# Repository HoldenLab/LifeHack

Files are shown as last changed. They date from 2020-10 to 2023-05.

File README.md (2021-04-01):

# LifeHack
**Open source SMLM microscope designs**

This GitHub repository contains all the designs needed to construct and set up your own version of the LifeHack microsope.

The full microscope CAD designs are available to view online and download through Autodesk's A360.com platform.

<a href="https://a360.co/34cZwOU">View CAD Design Online</a>

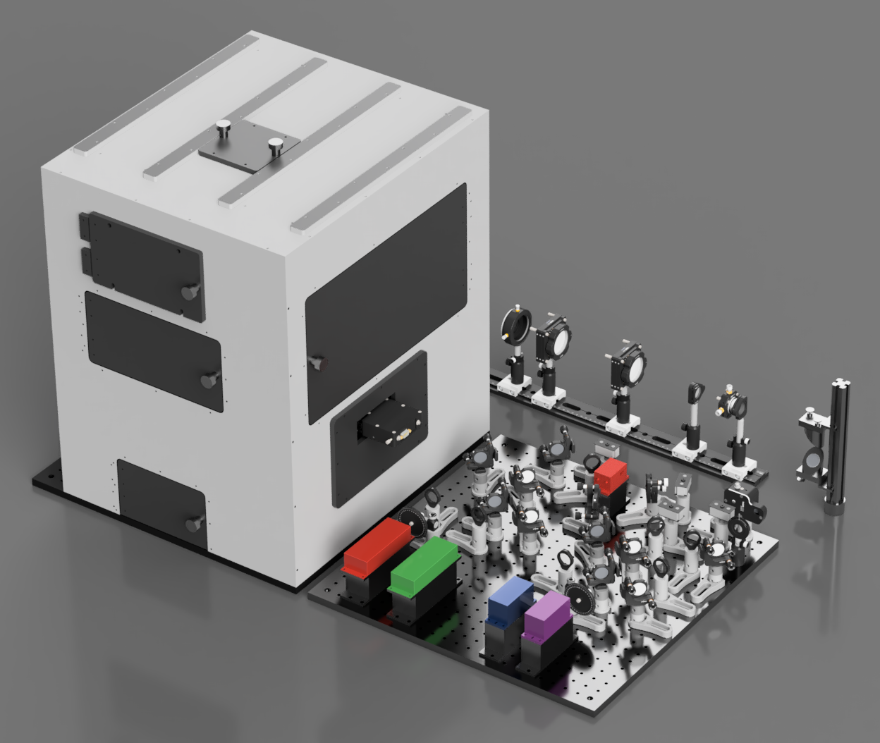
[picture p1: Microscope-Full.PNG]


The LifeHack microscope is an open-source system designed to provide an easily modifiable, modular platform for live cell SMLM imaging. It has been contructed from comercially available and 3D printed parts to simply the build process while retaining adaptability.

For full documentation please see the <a href="">LifeHack website</a>

### Change Log

  <ul>
    <li><b>24th February 2021:</b> Initial release of all modules </li>
    <li><b>1st April 2021:</b> Reduced diameter of 100mm beam expansion lens from 2" to 1"</li>
  </ul>

<br />This work is licensed under a <a rel="license" href="http://creativecommons.org/licenses/by-nc-sa/4.0/">Creative Commons Attribution-NonCommercial-ShareAlike 4.0 International License</a>.

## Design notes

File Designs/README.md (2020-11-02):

# Designs

This folder contains the necessary designs to replicate the LifeHack microscope system. The included subfolders contain; [3D Models](https://github.com/Joshedwards222/LifeHack/blob/master/Designs/CAD) intended as the main reference point for any build, [Line Diagrams](https://github.com/Joshedwards222/LifeHack/blob/master/Designs/Line_drawings) to show the principles of operation optically and electronically, and a full list of [Parts](https://github.com/Joshedwards222/LifeHack/blob/master/Designs/Parts) and induvidual designs for 3D printable components.

## LifeHack Build/Alignment Tips

### Contents
* [Using This Document](https://github.com/Joshedwards222/LifeHack/blob/master/Designs/README.md#using-this-document)
* [Main Body](https://github.com/Joshedwards222/LifeHack/blob/master/Designs/README.md#main-body)
    * [Infinity Cubes](https://github.com/Joshedwards222/LifeHack/blob/master/Designs/README.md#infinity-cubes)
* [Excitation Module](https://github.com/Joshedwards222/LifeHack/blob/master/Designs/README.md#excitation-module)
* [Beam Expansion Module](https://github.com/Joshedwards222/LifeHack/blob/master/Designs/README.md#beam-expansion-module)
* [Connecting Modules](https://github.com/Joshedwards222/LifeHack/blob/master/Designs/README.md#connecting-modules)
* [Incubation Box/Heater](https://github.com/Joshedwards222/LifeHack/blob/master/Designs/README.md#incubation-box/heater)
    * [Air Diffusers](https://github.com/Joshedwards222/LifeHack/blob/master/Designs/README.md#air-diffusers)
    * [Adding the Box to the System](https://github.com/Joshedwards222/LifeHack/blob/master/Designs/README.md#adding-the-box-to-the-system)
    * [Heater Setup](https://github.com/Joshedwards222/LifeHack/blob/master/Designs/README.md#heater-setup)
### Using This Document

This document is designed to supplement the 3D model of the microscope not as a stand alone instruction manual. A basic level of experience in building and aligning optical systems is assumed so only areas where the build process deviates from what would be considered standard practice are specifically included.

For elements of the build relating to controlling commercially available components such as electrical connections and software please refer to the relevant manual.

### Main Body

Alignment of the main body of the microscope is greatly aided by the use of a dedicated alignment laser with interchangeable screw mounts. This allows for mounting of the laser at various ports and on sections of rail.

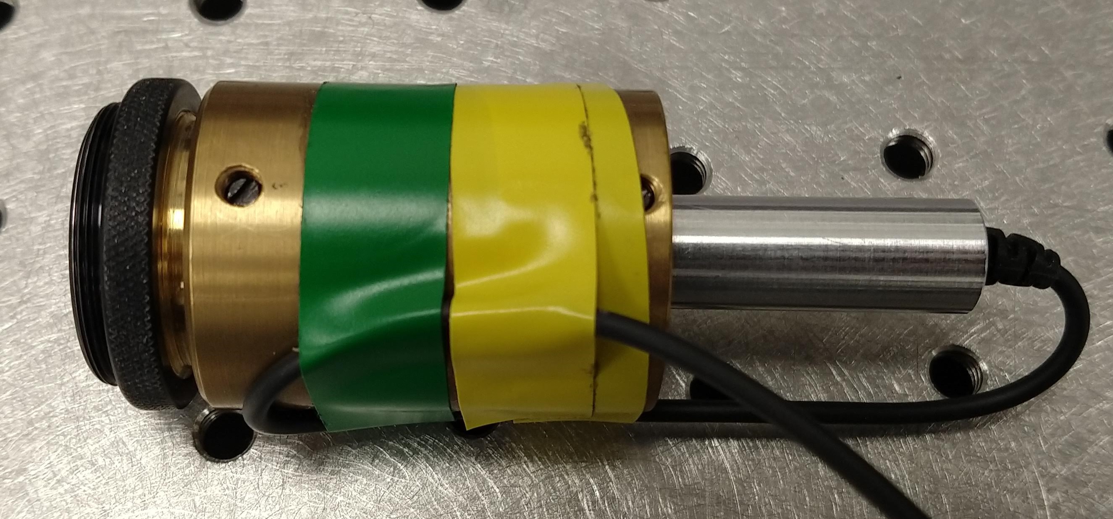
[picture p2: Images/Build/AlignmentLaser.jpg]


#### Infinity Cubes

The two vertically mounted Infinity Cubes need to have their filter cubes mounted the other way up to standard. To achieve this the top and bottom plates need to be removed and swapped before fitting in to the microscope.

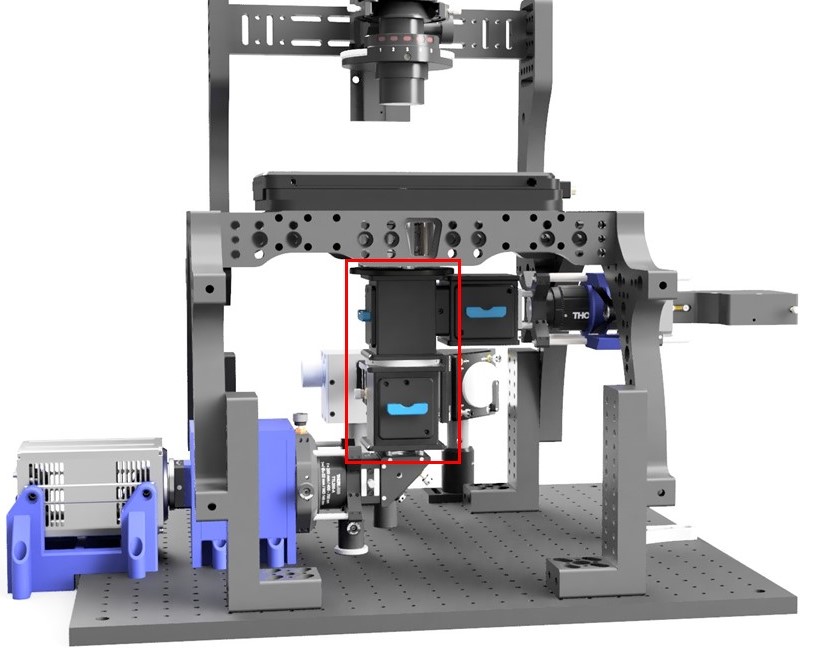
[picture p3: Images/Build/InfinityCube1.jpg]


The desired set up can be found in the microscope 3D model.

### Excitation Module

This module can be aligned with the lasers in the design by usual techniques.

### Beam Expansion Module

This module is best aligned using the output from the excitation module and as such should be built following that module. Alignment can be conducted with usual techniques.

### Connecting Modules

As the Main Body and Excitation modules are self contained on boards they can be built and then moved into place if convenient. Once the three modules are aligned individually and in place they need to be aligned to eachother. Assuming you have already used the Excitation Module to align the Beam Expansion Module these only need aligning collectively to the Main Body. To do this it can be useful to use the alignment laser mounted in the Main Body and a laser from the Excitation Module to give opposing beams through the system.

### Incubation Box/Heater

* After checking that you are in possession of the full set of parts tap every M4 sized hole (the electric screwdriver is a big time saver for this).
* item Before connecting the main panels together, first attach each subsidiary panel to its respective main face. 
* Following this, now attach the 5 main panels together to confirm the parts fit correctly.
* Remove the top panel and attach the felt air diffusers as shown below.

#### Air Diffusers

* Remove the "top filter mounts" from the top panel to reveal the slits beneath.
* Measure and cut the diffuser felt to fit the slits.

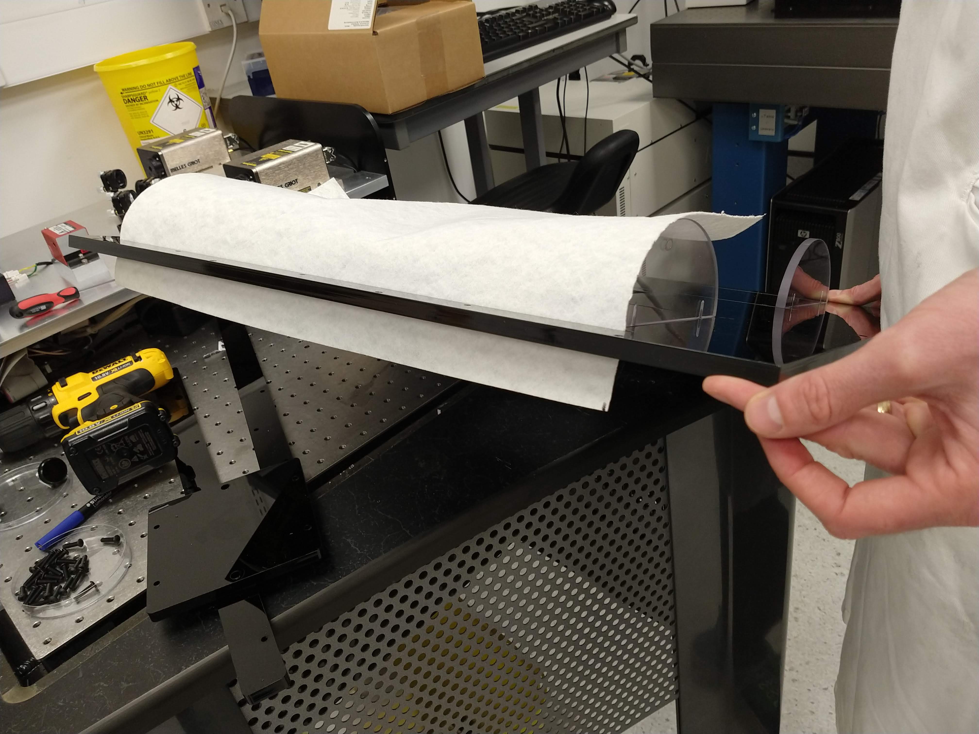
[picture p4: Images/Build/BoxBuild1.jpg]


* Pull the diffuser a short way through one of the slits and re attach the corresponding "top filter mount" to hold it in place.
* To do this, pull the diffuser to one side and attach the row of screws on the opposite side. 
* Then, using a screwdriver or similar, poke through the holes on the other side to put holes through the diffuser material and attache the screws on this side

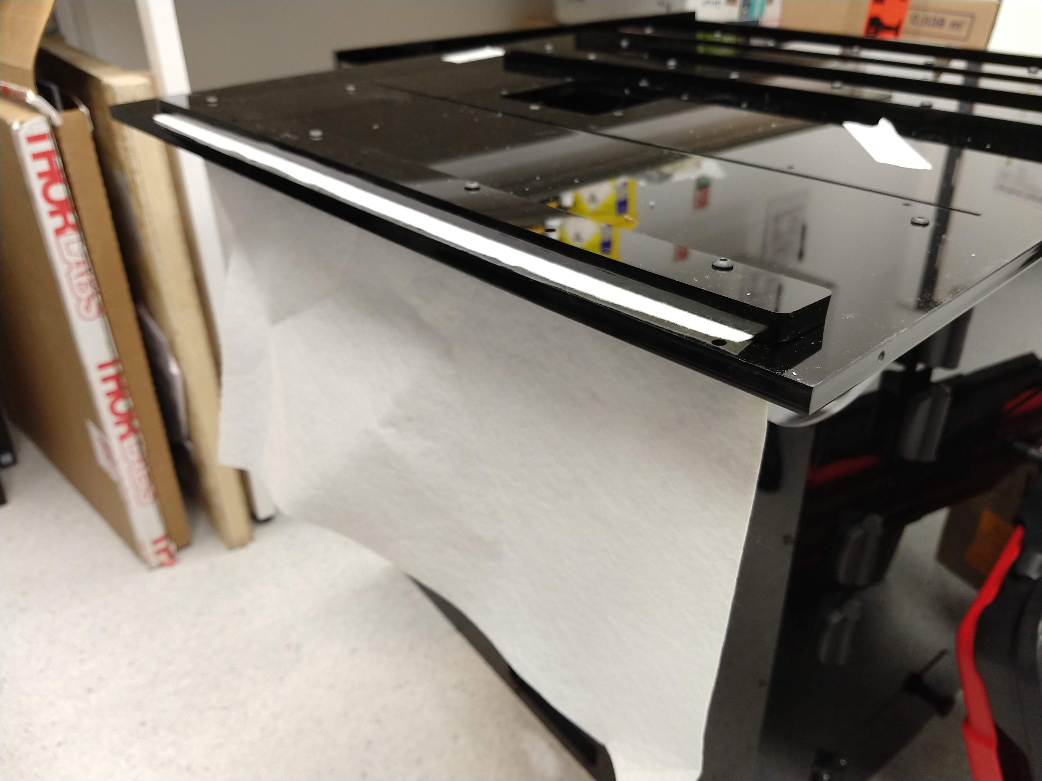
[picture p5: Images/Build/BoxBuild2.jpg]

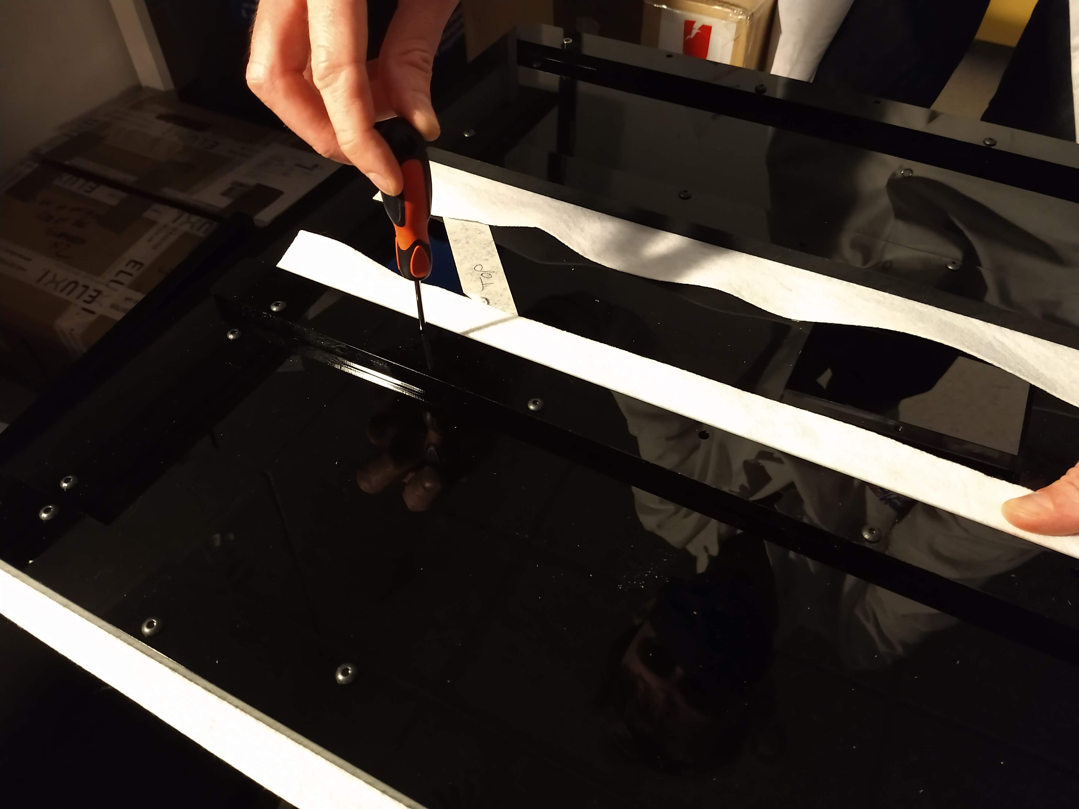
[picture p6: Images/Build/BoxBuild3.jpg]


\begin{figure}[H]
\begin{minipage}{.5\textwidth}
    \centering
        \includegraphics[width=7cm]{Figures/BoxBuild2.jpg}
        \caption{}
\end{minipage}
\begin{minipage}{.5\textwidth}
\centering
        \includegraphics[width=7cm]{Figures/BoxBuild3.jpg}
        \caption{}
\end{minipage}
\end{figure}

* Pull the loose side of the diffuser across the D-shaped diffuser mounts and pass it through the slit on the other side.
* Pull the diffuser taught across the mounts to ensure a good fit and secure it with the corresponding "top filter mount".

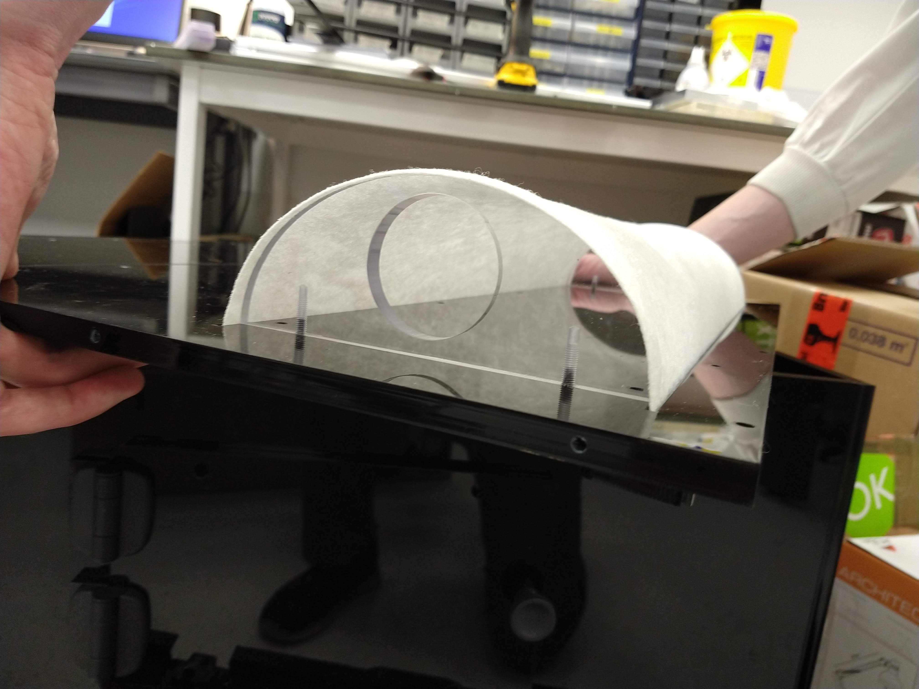
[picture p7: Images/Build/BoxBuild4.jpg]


* Repeat the above steps for the second diffuser then reattach the now completed top panel to the rest of the box. 

#### Adding the Box to the system

\begin{center}

**This is a two person job**

\end{center}

* Check the box is securely assembled before lifting.
* Open hatch doors on the two side panels and remove the "top cover" on the top panel to provide handholds.
* Remove the camera and CRISP units from the microscope "main body".
* Lift the box over the top of the "main body" and gently set it down.

#### Heater Setup

* Remove the "Back Air-hose Covers" from the box.
* Using Epoxy, for each cover attach the flared air-hose connector.

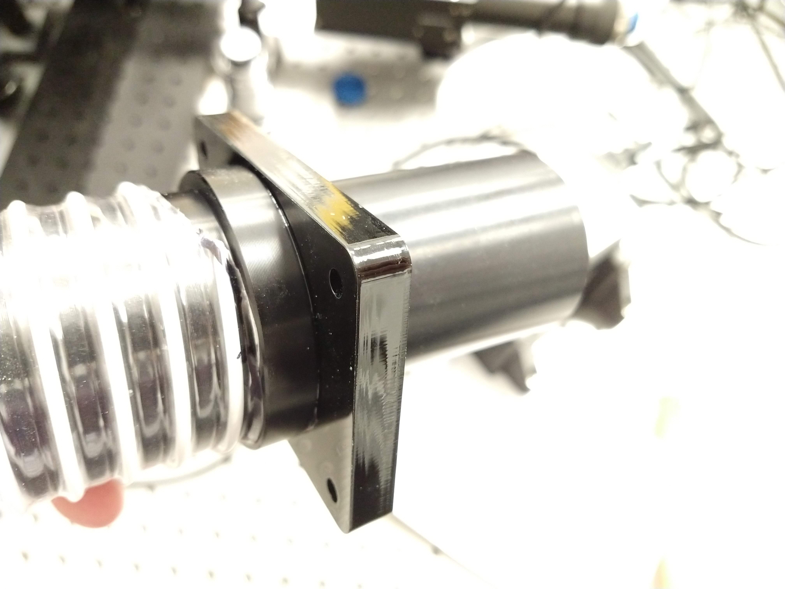
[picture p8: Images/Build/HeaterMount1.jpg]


* Allow this to set for about 20 minutes (refer to epoxy for precise time).
* For the top two "Back Air-hose covers", use the Epoxy to attach the non-flared air hose connectors from the opposite side to the flared connector.

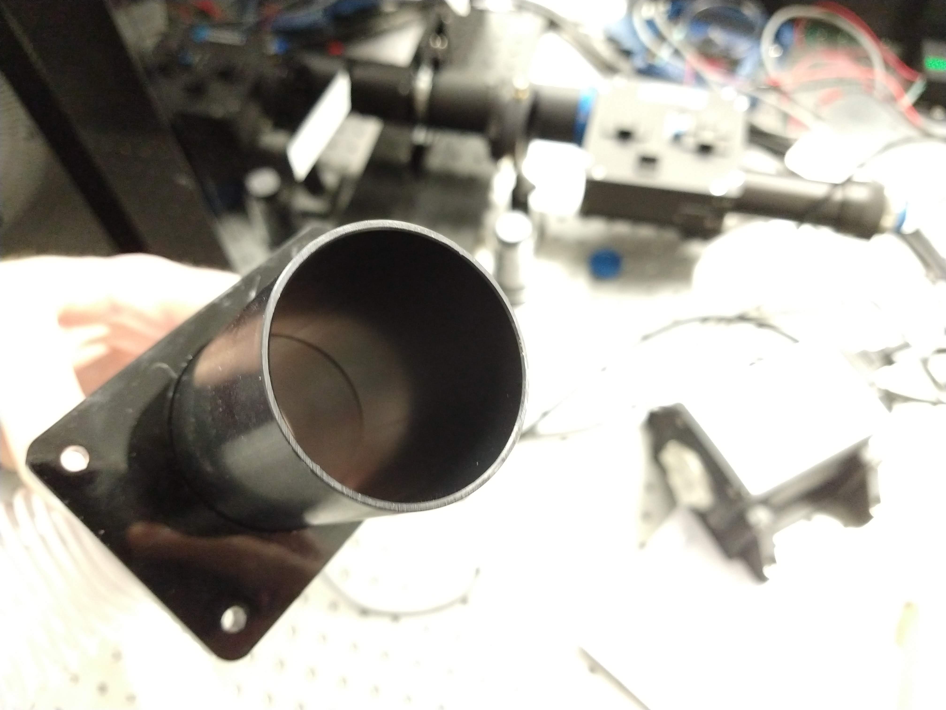
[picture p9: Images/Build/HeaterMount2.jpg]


* Leave the 4 assemblies to set for 3 hours (refer to epoxy for precise time).
* Before reattaching the assemblies to the back of the box, measure and cut the air-hose to length for each of the 4 connections.

**PUT PHOTO OF CUTTING HERE**

* Once cut, attach the air-hoses to the heater and then to the attachment assemblies (Utilise a screwing action following the direction of the structural wire in the air hose).

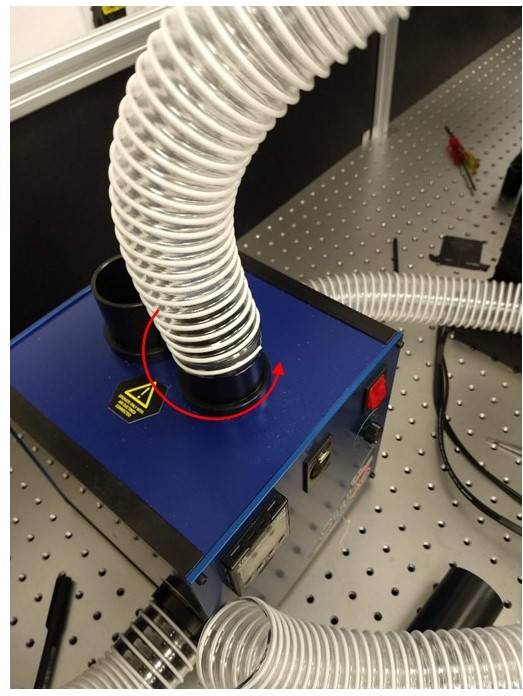
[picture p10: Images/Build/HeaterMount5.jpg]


\begin{figure}[H]
    \centering
        \includegraphics[width=10cm]{Figures/HeaterMount5.jpg}
        \caption{}
\end{figure}

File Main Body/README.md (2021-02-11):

# Main Body

This folder contains everything needed to build the Main Body. This also encompasses the Image Autofocus and Focus Shifter sub-modules

<a href="https://a360.co/3p1nkNR">View CAD Design</a> through A360.com

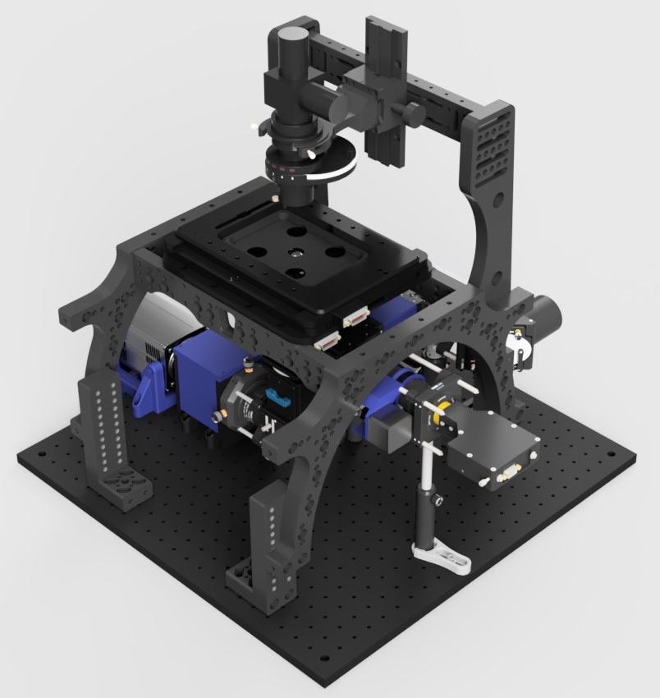
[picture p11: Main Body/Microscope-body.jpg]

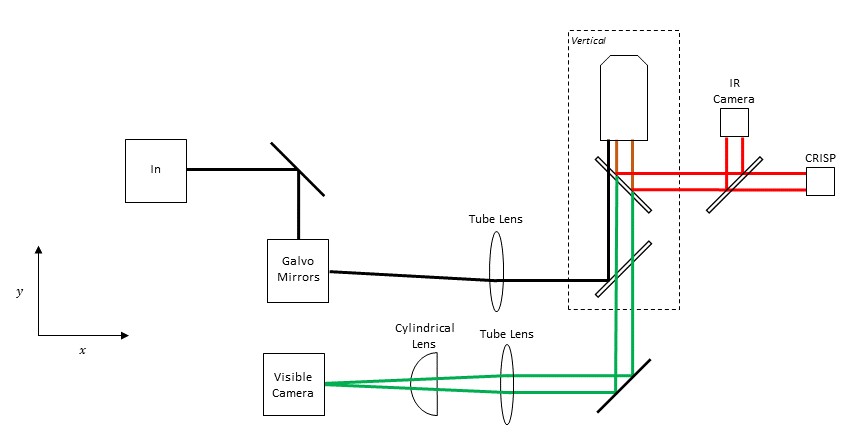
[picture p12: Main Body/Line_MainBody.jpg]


## Parts

Contains .STL files for the 3D printed components. 3D printed parts were printed on an Ultimaker 2+ using PLA with triangular infill at 30% density

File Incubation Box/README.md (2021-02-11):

# Incubation Box

This folder contains everything needed to build the Incubation box

<a href="https://a360.co/38g8Djh">View CAD Design</a> through A360.com

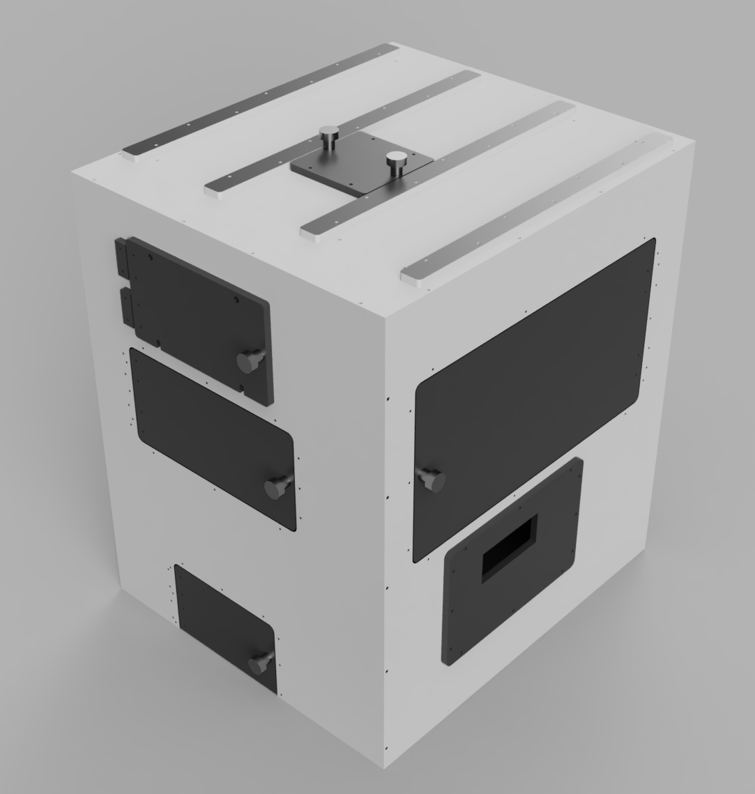
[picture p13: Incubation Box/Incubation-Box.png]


## Parts

Contains dimentioned 2D drawings of box components in .DXF form ready for production.

All parts are made from Black 9961 Perspex except the window which is made from clear Perspex.

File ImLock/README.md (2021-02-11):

# Image Autofocus Module

This folder contains everything needed to build the Image Autofocus module

<a href="https://a360.co/3p8be5k">View CAD Design</a> through A360.com

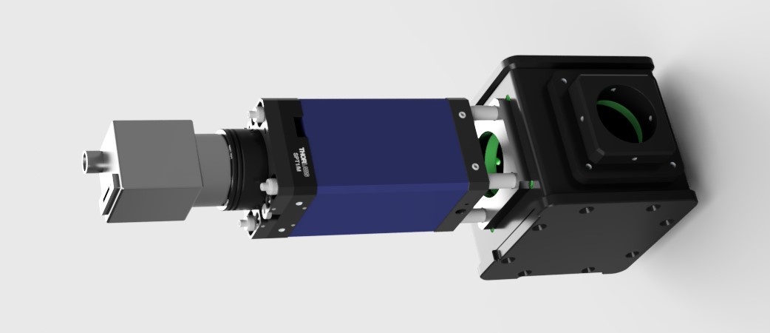
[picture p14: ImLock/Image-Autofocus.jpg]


## Parts

Contains .STL files for the 3D printed components. 3D printed parts were printed on an Ultimaker 2+ using PLA with triangular infill at 30% density.

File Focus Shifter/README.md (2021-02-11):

# FocusShifter: Arduino-based microscope autofocus control

This folder contains everything needed to build the Focus Shifter module

<a href="https://a360.co/3rbyG3y">View CAD Design</a> through A360.com

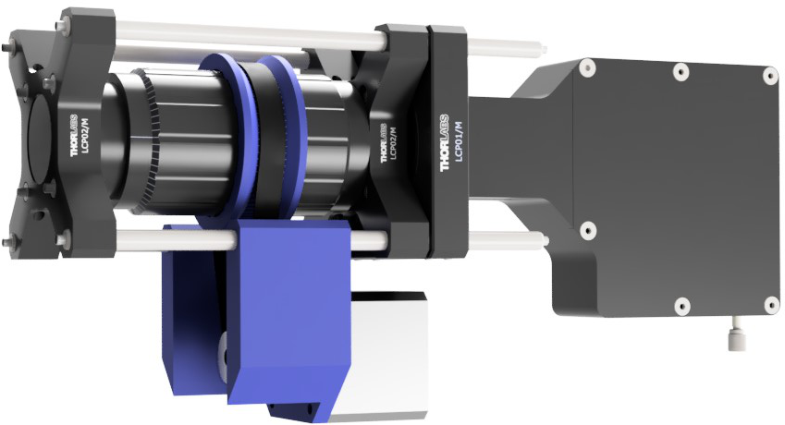
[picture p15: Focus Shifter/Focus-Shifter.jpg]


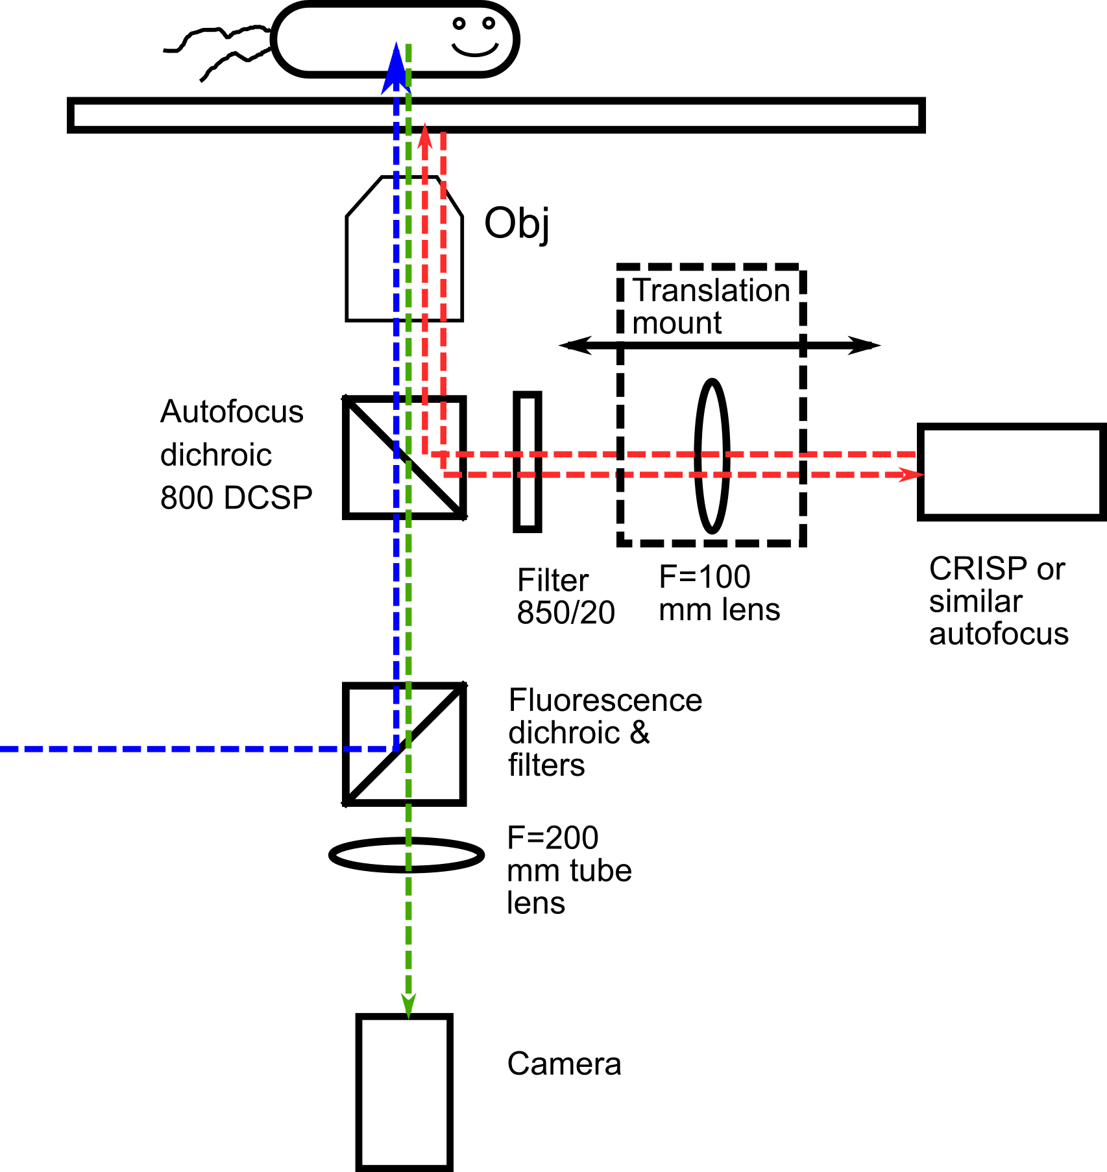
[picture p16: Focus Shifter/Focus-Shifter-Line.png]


## Parts

Contains .STL files for the 3D printed components. 3D printed parts were printed on an Ultimaker 2+ using PLA with triangular infill at 30% density.

## Software

Contains arduino control software.

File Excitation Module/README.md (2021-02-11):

# Excitation Module

This folder contains everything needed to build the excitation module

<a href="https://a360.co/3mF2ceR"> View CAD Design</a> through A360.com

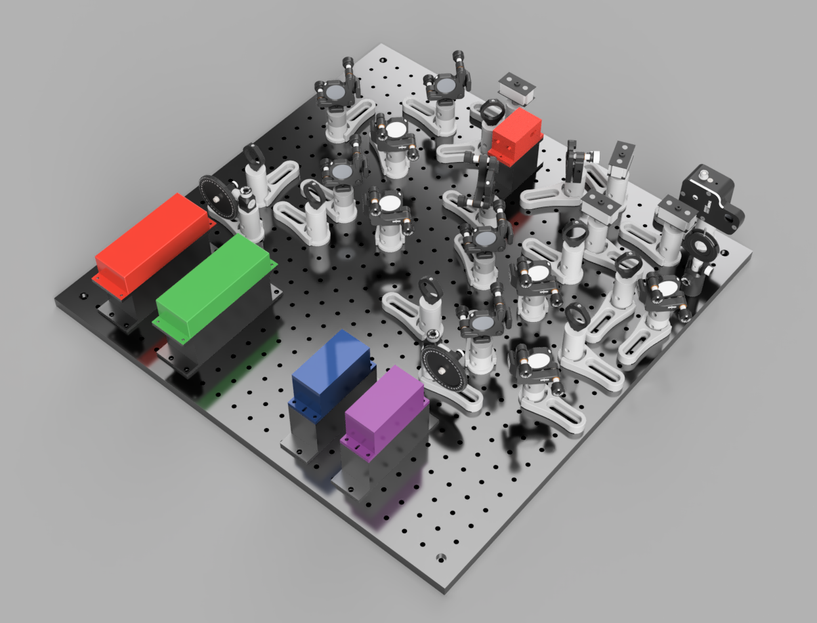
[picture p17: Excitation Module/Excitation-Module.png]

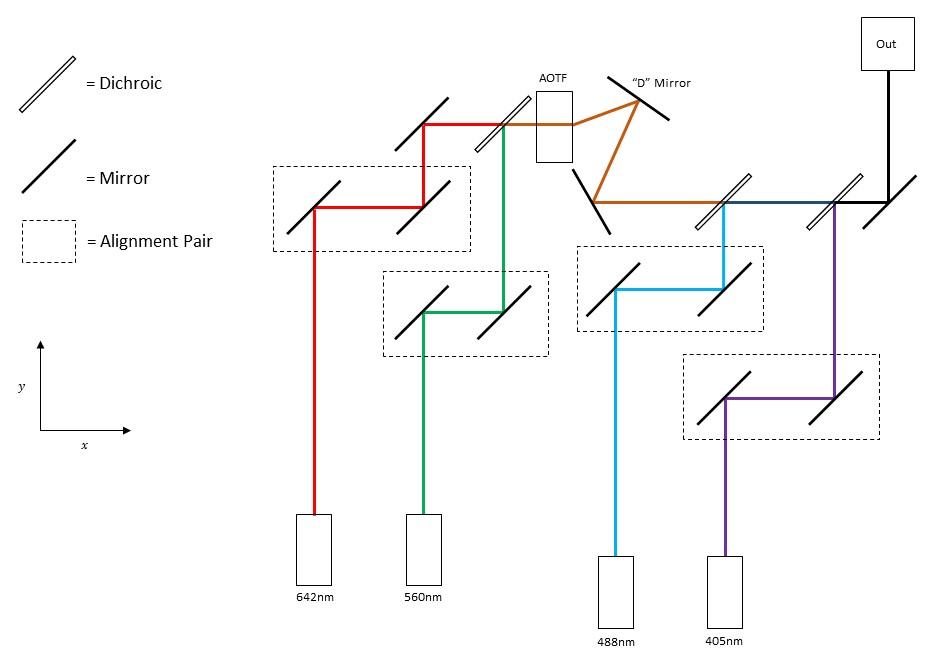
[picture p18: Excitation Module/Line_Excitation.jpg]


## Parts

Contains .STL files for the 3D printed components. 3D printed parts were printed on an Ultimaker 2+ using PLA with triangular infill at 30% density

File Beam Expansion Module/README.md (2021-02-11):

# Beam Expansion Module

This folder contains everything needed to build the Beam Expansion Module

<a href="https://a360.co/3h2i9KU">View CAD Design</a> through A360.com

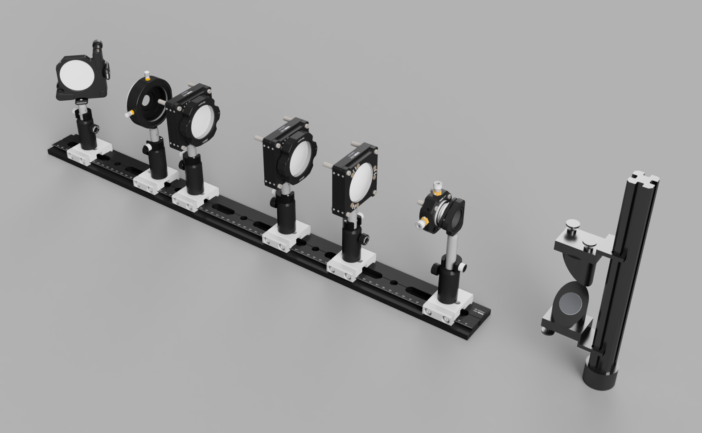
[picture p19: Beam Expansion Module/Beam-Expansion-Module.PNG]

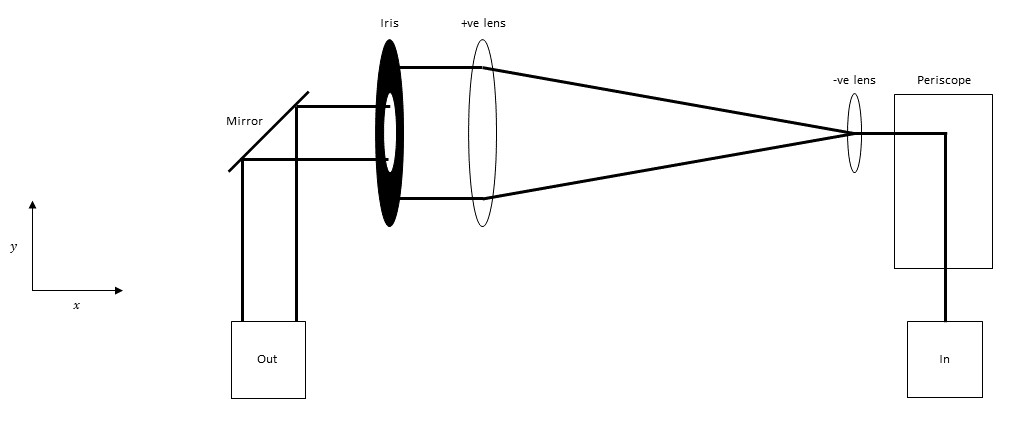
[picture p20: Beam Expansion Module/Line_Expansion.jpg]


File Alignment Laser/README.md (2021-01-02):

# Alignment Laser

Designs for a laser mount to allow for attachment to the system via an RMS thread

<image src="AlignmentLaser.jpg" width=500px>

Adapted from Design in <a href="https://www.osapublishing.org/oe/fulltext.cfm?uri=oe-23-6-7734&id=313825">S. Abrahamsson et al, "MultiFocus Polarization Microscope (MF-PolScope) for 3D polarization imaging of up to 25 focal planes simultaneously," Opt. Express 23, 7734-7754 (2015)</a>

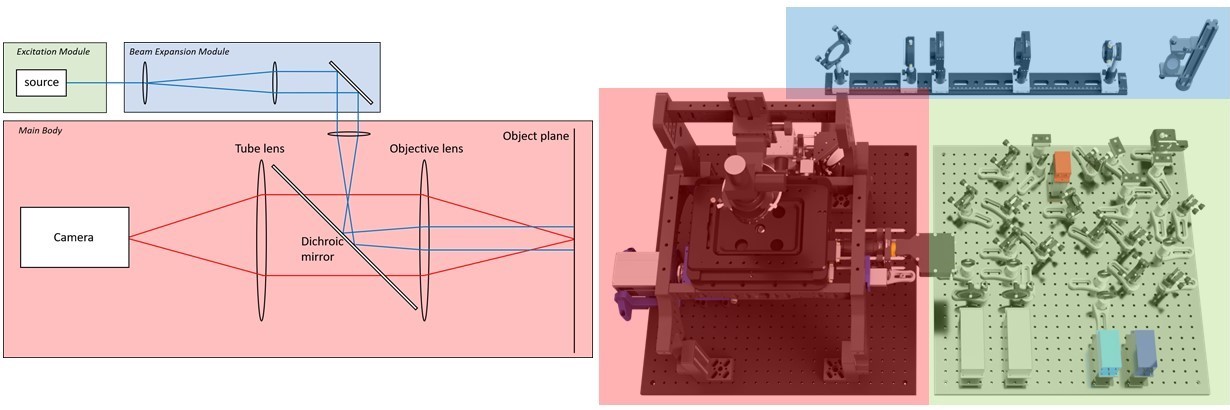
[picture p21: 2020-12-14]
Module-Structure.jpg

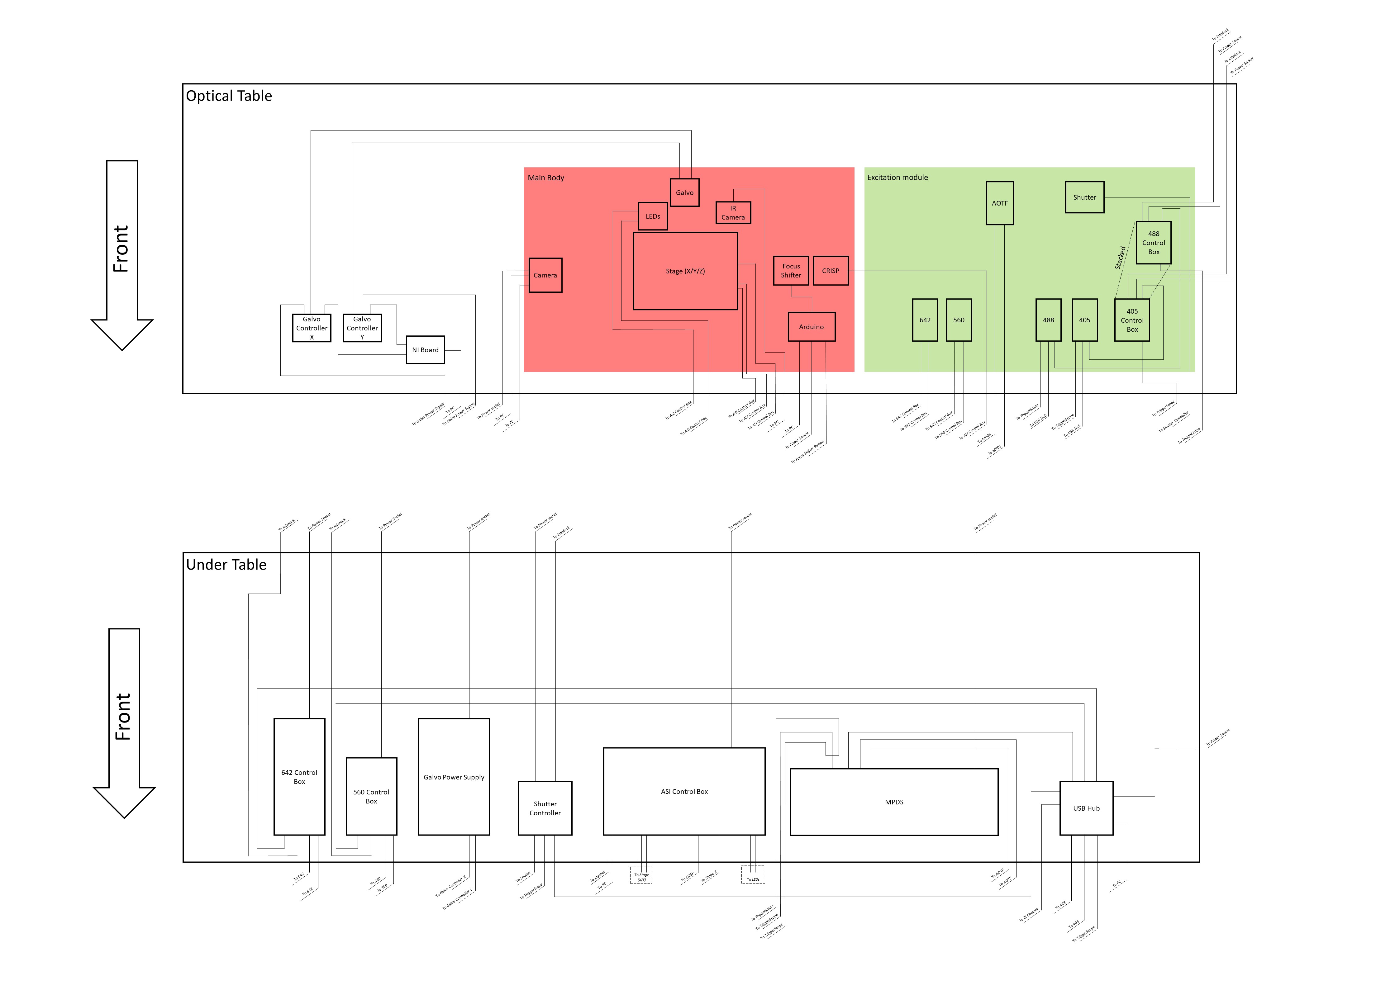
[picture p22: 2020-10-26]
Modules/Circuit Diagram.jpg

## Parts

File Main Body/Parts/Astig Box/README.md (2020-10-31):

# Astigmatic Lens Box

The body of the box should be printed in the same orientation as it sits in the microscope but the lid should be printed upside down with the top face against the build plate

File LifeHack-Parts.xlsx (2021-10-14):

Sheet: Excitation Module
Parts List
 | Part number | Supplier | Quantity | Price | Subtotal
Breadboard baseplate 600 mm | 715-6060-BL | EKSMA | 1 | £546.00 | £546.00
KINEMATIC MIRROR
kinematic mirror mount (KM) | KM100CP/M | Thorlabs | 11 | £53.93 | £593.23
pillar post,Ø 25mm, L19mm,M6 tap,M4 adaptot included | RS19/M | Thorlabs | 11 | £13.69 | £150.59
pedestal pillar post,Ø 25mm,M6taps,L25mm | RS1P/M | Thorlabs | 11 | £17.21 | £189.31
clamp for KM | CF125 | Thorlabs | 11 | £6.71 | £73.81
Ø1" Broadband Dielectric Mirror, 400 - 750 nm, 10 Pack | BB1-E02-10 | Thorlabs | 1 | £506.93 | £506.93
Ø1" Broadband Dielectric Mirror, 400 - 750 nm | BB1-E02 | Thorlabs | 1 | £56.33 | £56.33
OPTIC HOLDER
Fixed, Ø 1inch, mirror mount, M4 tap | FMP1/M | Thorlabs | 7 | £12.09 | £84.63
pedestal pillar post,Ø 25mm,M6taps,L50mm | RS2P/M | Thorlabs | 7 | £20.46 | £143.22
Post Spacer, Ø25 mm, Thickness = 4mm | RS4M | Thorlabs | 7 | £5.58 | £39.06
clamp for OH | CF125 | Thorlabs | 7 | £6.71 | £46.97
HALF-MIRROR/D Mirror
Left-Handed Kinematic Mount for Ø1" D-Shaped Mirrors | KM100DL | Thorlabs | 1 | £62.69 | £62.69
pedestal pillar post,Ø 25mm,M6taps,L38mm | RS1.5P/M | Thorlabs | 1 | £20.46 | £20.46
Post Spacer, Ø25 mm, Thickness = 6mm | RS6M | Thorlabs | 1 | £5.78 | £5.78
clamp for HM | CF125 | Thorlabs | 1 | £6.71 | £6.71
Ø1" Broadband Dielectric D-Shaped Mirror, 400 - 750 nm | BBD1-E02 | Thorlabs | 1 | £64.42 | £64.42
BEAM DUMPS
Beam Block, 400 - 700 nm, 10 WPower, CW Only, Includes TR75/M Post | LB1/M | Thorlabs | 4 | £37.87 | £151.48
Pedestal Pillar Post, Ø25.0 mm,M6 Taps, L = 50 mm | RS2P/M | Thorlabs | 4 | £21.61 | £86.44
Post Spacer, Ø25 mm, Thickness = 7mm | RS7M | Thorlabs | 4 | £5.13 | £20.52
clamp for BD | CF125 | Thorlabs | 4 | £6.71 | £26.84
Adapter with Internal M4 x 0.7 Threads and External M6 x 1.0 Threaded Stud | AS4M6M | Thorlabs | 4 | £3.40 | £13.60
Updated ELECTRONIC SHUTTER
Optical Beam Shutter with 10' Long Cable, Ø1/2" Aperture, M4 Tap | SH05/M | Thorlabs | 1 | £363.25 | £363.25
K-Cube Solenoid Controller (Power Supply Not Included) | KSC101 | Thorlabs | 1 | £451.49 | £451.49
15 V, 2.4 A Power Supply Unit with 3.5 mm Jack Connector for One K- or T-Cube | KPS101 | Thorlabs | 1 | £25.75 | £25.75
pedestal pillar post,Ø 25mm,M4taps,L50mm | RS2P4M | Thorlabs | 1 | £19.48 | £19.48
clamp for ES | CF125 | Thorlabs | 1 | £6.71 | £6.71
ND filters
Mounted Continuously Variable ND Filter, Ø50 mm, OD: 0-4.0, ARC: 350 - 700nm | NDC-50C-4M-A | Thorlabs | 2 | £387.95 | £775.90
Pedestal Pillar Post, M6 Taps, L = 50 mm | RS2P/M | Thorlabs | 2 | £21.71 | £43.42
Right-Angle End Clamp for Ø1/2" Posts, M6 Stud and 5 mm Hex | RA180/M | Thorlabs | 2 | £8.60 | £17.20
Ø12.7 mm Optical Post, SS, M4 Setscrew, M6 Tap, L = 30 mm | TR30/M | Thorlabs | 2 | £3.66 | £7.32
clamp for ND | CF125 | Thorlabs | 2 | £6.71 | £13.42
IRIS
Iris | ID25/M | Thorlabs | 1 | £45.65 | £45.65
Ø1/2" Post Holder | PH40/M | Thorlabs | 1 | £5.58 | £5.58
Ø1/2" Post | TR40/M | Thorlabs | 1 | £3.84 | £3.84
M6 Setscrew (5 pack) | SS6MS12 | Thorlabs | 1 | £4.58 | £4.58
Post Collar | R2M | Thorlabs | 1 | £3.85 | £3.85
Locator Screws
Adapter with External M6 x 1.0 Threads and External M4 x 0.7 Threads | AP6M4M | Thorlabs | 24 | £1.58 | £37.92
Excitation filters -chroma
405nm notch filter | ZET405/20X | Chroma | 1 | £237.00 | £237.00
488nm notch filter | ZET488/10x | Chroma | 1 | £237.00 | £237.00
561nm notch filter | ZET561/10x | Chroma | 1 | £237.00 | £237.00
642nm notch filter | ZET642/20x | Chroma | 1 | £237.00 | £237.00
Excitation dichroics
561/642 Dichroic combiner Ø25mm | DCM14 | Newport | 1 | £208.00 | £208.00
488/561 Dichroic combiner Ø25mm | DCM12 | Newport | 1 | £208.00 | £208.00
405/488 Dichroic combiner Ø25mm | DCM10 | Newport | 1 | £208.00 | £208.00
Custom mounts
405 nm mount | - | Protolabs | 1 | £192.20 | £192.20
488 nm mount | - | Protolabs | 1 | £192.20 | £192.20
561 nm mount | - | 3D printed | 1 | £0.00 | £0.00
642 nm mount | - | 3D printed | 1 | £0.00 | £0.00
AOTF mount | - | 3D printed | 1 | £0.00 | £0.00
Lasers
Stradus 405nm 100mW | 11098 | Laser 2000 | 1 | £4350.00 | £4350.00
Stradus 488nm 150mW | 11101 | Laser 2000 | 1 | £7650.00 | £7650.00
MPB Visible Fibre Laser 560nm, 300mW OEM | VFL-P-300-560-OEM1-B1 | Eluxi | 1 | £15717.75 | £15717.75
MPB Visible Fibre Laser 642nm, 1W OEM | VFL-P-1000-642-OEM1-B1 | Eluxi | 1 | £9036.00 | £9036.00
MPB External Power Supply For VFL | VFL-POWER-SUPPLY-150 | Eluxi | 2 | £350.00 | £700.00
AOTF
AOTF | AOTFnC-400.650-TN | Photon Lines | 1 | £2250.00 | £2250.00
MPDS, AOTF Driver | MPDS8C-D66-22-xx.xx | Photon Lines | 1 | £3035.00 | £3035.00
RF cable, SMA-SMA, 2m | CBL-SAM200SAM-RG223 | Photon Lines | 1 | £16.00 | £16.00
RSTAB cable, SMC-SMC, 2m | CBL-SCF200SCF-RG316 | Photon Lines | 1 | £26.00 | £26.00
TOTAL |  |  |  |  | £49451.53

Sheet: Beam Expansion Module
 | Supplier | Part number | Price | Quantity | Subtotal | Notes
Periscope
Rail Periscope, 8.9 in. Height, 1 in. Mirrors, Magnetic Pedestal Base | Newport | BSD-2R | £528 | 1 | £528.00
Ø1" Broadband Dielectric Mirror, 400 - 750 nm | Thorlabs | BB1-E02 | £58.01 | 2 | £116.02
Negative Lens
30 mm Cage System, XY Translating Lens Mount for Ø1" Optics | Thorlabs | CXY1 | £140.40 | 1 | £140.40
Ø12.7 mm Post Holder, Spring-Loaded Hex-Locking Thumbscrew, L=50 mm | Thorlabs | PH50/M | £5.95 | 1 | £5.95
Coupler, External Threads, 0.5" Long | Thorlabs | SM1T2 | £16.16 | 1 | £16.16
Magnetic Quick-Release Carriage Set, M4 Tap | Thorlabs | KB1P/M | £39.77 | 1 | £39.77
M6 x 1.0 Stainless Steel Setscrew with Hex on Both Ends, 16 mm Long, Pack of 10 | Thorlabs | SS6M16D | £9.18 | 1 | £9.18
Low-Profile T-Nut, M6 Tapped Hole, Qty: 10 | Thorlabs | XE25T3/M | £7.96 | 1 | £7.96
Ø12.7 mm Optical Post, SS, M4 Setscrew, M6 Tap, L = 75 mm | Thorlabs | TR75/M | £4.19 | 1 | £4.19
Clamping Platform for 66 mm Rails, 1/4" Counterbored Slot, 40 mm Long | Thorlabs | XT66C4 | £22.73 | 1 | £22.73
Ø1" OD Adapter for Ø1/2" Optic, 0.25" Thick | Thorlabs | AD1 | £12.42 | 1 | £12.42
f = -30.0 mm, Ø1/2" Achromatic Doublet, ARC: 400 - 700 nm | Thorlabs | ACN127-030-A | £46.07 | 1 | £46.07
Post Collar (5 pack) | Thorlabs | R2/M-P5 | £19.31 | 1 | £19.31
Positive Lens
60 mm Cage Plate, SM2 Threads, 0.5" Thick, M4 Tap (Two SM2RR Retaining Rings Included) | Thorlabs | LCP01/M | £30.84 | 2 | £61.68
60 mm Removable Cage Plate | Thorlabs | LCP90F | £52.97 | 2 | £105.94
Ø12.7 mm Post Holder, Spring-Loaded Hex-Locking Thumbscrew, L=50 mm | Thorlabs | PH50/M | £5.95 | 2 | £11.90
Ø12.7 mm Optical Post, SS, M4 Setscrew, M6 Tap, L = 50 mm | Thorlabs | TR50/M | £4.01 | 2 | £8.02
M6 x 1.0 Stainless Steel Setscrew with Hex on Both Ends, 16 mm Long, Pack of 10 | Thorlabs | SS6M16D | £9.18 | 0 | £0.00 | Multipack in Negative lens section
Low-Profile T-Nut, M6 Tapped Hole, Qty: 10 | Thorlabs | XE25T3/M | £7.96 | 0 | £0.00 | Multipack in Negative lens section
Clamping Platform for 66 mm Rails, 1/4" Counterbored Slot, 40 mm Long | Thorlabs | XT66C4 | £22.73 | 2 | £45.46
f = 200.0 mm, Ø2" Achromatic Doublet, ARC: 400 - 700 nm | Thorlabs | AC508-200-A | £84.41 | 1 | £84.41
f = 400.0 mm, Ø2" Achromatic Doublet, ARC: 400 - 700 nm | Thorlabs | AC508-400-A | £84.41 | 1 | £84.41
Post Collar | Thorlabs | R2/M | £3.86 | 0 | £0.00 | Multipack in Negative lens section
Small Positive lens
Ø12.7 mm Post Holder, Spring-Loaded Hex-Locking Thumbscrew, L=50 mm | Thorlabs | PH50/M | £5.95 | 1 | £5.95
Magnetic Quick-Release Carriage Set, M4 Tap | Thorlabs | KB1P/M | £39.77 | 1 | £39.77
M6 x 1.0 Stainless Steel Setscrew with Hex on Both Ends, 16 mm Long, Pack of 10 | Thorlabs | SS6M16D | £9.18 | 0 | £0.00 | Multipack in Negative lens section
Low-Profile T-Nut, M6 Tapped Hole, Qty: 10 | Thorlabs | XE25T3/M | £7.96 | 0 | £0.00 | Multipack in Negative lens section
Ø12.7 mm Optical Post, SS, M4 Setscrew, M6 Tap, L = 75 mm | Thorlabs | TR75/M | £4.19 | 1 | £4.19
Clamping Platform for 66 mm Rails, 1/4" Counterbored Slot, 40 mm Long | Thorlabs | XT66C4 | £22.73 | 1 | £22.73
Post Collar | Thorlabs | R2/M | £3.86 | 0 | £0.00 | Multipack in Negative lens section
f = 100 mm, Ø1" Achromatic Doublet, ARC: 400 - 700 nm | Thorlabs | AC254-100-A | £60.87 | 1 | £60.87
Iris
Translating Lens Mount for Ø2" Optics, 1 Retaining Ring Included, Metric | Thorlabs | LM2XY/M | £122.55 | 1 | £122.55
SM2 Ring-Actuated Iris Diaphragm (Ø1 - Ø25 mm) | Thorlabs | SM2D25D | £67.16 | 1 | £67.16
Ø12.7 mm Post Holder, Spring-Loaded Hex-Locking Thumbscrew, L=50 mm | Thorlabs | PH50/M | £5.95 | 1 | £5.95
Ø12.7 mm Optical Post, SS, M4 Setscrew, M6 Tap, L = 50 mm | Thorlabs | TR50/M | £4.01 | 1 | £4.01
M6 x 1.0 Stainless Steel Setscrew with Hex on Both Ends, 16 mm Long, Pack of 10 | Thorlabs | SS6M16D | £9.18 | 0 | £0.00 | Multipack in Negative lens section
Low-Profile T-Nut, M6 Tapped Hole, Qty: 10 | Thorlabs | XE25T3/M | £7.96 | 0 | £0.00 | Multipack in Negative lens section
Clamping Platform for 66 mm Rails, 1/4" Counterbored Slot, 40 mm Long | Thorlabs | XT66C4 | £22.73 | 1 | £22.73
Post Collar | Thorlabs | R2/M | £3.86 | 0 | £0.00 | Multipack in Negative lens section
Mirror
Kinematic Mirror Mount for Ø2" Optics with Post-Centered Front Plate, M4 Taps | Thorlabs | KM200CP/M | £81.97 | 1 | £81.97
Ø12.7 mm Post Holder, Spring-Loaded Hex-Locking Thumbscrew, L=50 mm | Thorlabs | PH50/M | £5.95 | 1 | £5.95
Ø12.7 mm Optical Post, SS, M4 Setscrew, M6 Tap, L = 50 mm | Thorlabs | TR50/M | £4.01 | 1 | £4.01
M6 x 1.0 Stainless Steel Setscrew with Hex on Both Ends, 16 mm Long, Pack of 10 | Thorlabs | SS6M16D | £9.18 | 0 | £0.00 | Multipack in Negative lens section
Low-Profile T-Nut, M6 Tapped Hole, Qty: 10 | Thorlabs | XE25T3/M | £7.96 | 0 | £0.00 | Multipack in Negative lens section
Clamping Platform for 66 mm Rails, 1/4" Counterbored Slot, 40 mm Long | Thorlabs | XT66C4 | £22.73 | 1 | £22.73
Ø2" Broadband Dielectric Mirror, 400 - 750 nm | Thorlabs | BB2-E02 | £117.41 | 1 | £117.41
Post Collar | Thorlabs | R2/M | £3.86 | 1 | £3.86
Rail
66 mm Single Dovetail Rail with Mounting Counterbores, L = 750 mm | Thorlabs | XT66SD-750 | £79.57 | 1 | £79.57
Total |  |  |  |  | £2041.39

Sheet: Main Body
Part name | Part number | Supplier | Quantity | Price | Subtotal | Notes
Breadboard baseplate 600 mm | 715-6060-BL | EKSMA | 1 | £546.00 | £546.00
ASI RAMM US-2000current with basket+condenser
RAMM FULL WITH NEWER ABTS-1066 CROSS BAR + Riser for Condenser | DASI/RAMM-FULL | ASI | 1 | £2633.84 | £2633.84
ABTS-1031 STILT (4 Pack) | DASI/RAMM-STILTS | ASI | 1 | £321.20 | £321.20
LED Lamp | DASI/LLEDWHT-AI | ASI | 1 | £682.55 | £682.55
Beamsplitter Cube | DASI/C60-SHORT-PORT1 | ASI | 1 | £441.65 | £441.65
OLYMPUS CONDENSER BRACKET ASSEMBLY | DASI/OLY-TRANS-ILLUM | ASI | 1 | £3015.27 | £3015.27 | Include 850nm LED (no regulator)
Cairn-dichroic-ASI stage custom rig
Sample Holder | DASI/I-3091 | ASI | 1 | £301.13 | £301.13
Motorized Stage | DASI/US/PZ2500-IOM | ASI | 1 | £18047.43 | £18047.43 | Includes: Objective basket if requested through Cairn research
LifeHack TriCube | S1250/CLH/003 | Cairn research | 1 | £2250.00 | £2250.00 | Includes: 2x Infinity Cubes, 1x Combiner Cube, Required adaptations
Filter Cube | P290/000/200 | Cairn research | 5 | £292.63 | £1463.15
Nikon NA1.49 100x objective (CFI SR HP Apochromat TIRF 100XC Oil) | MRD0195 | Nikon | 1 | £12445.60 | £12445.60
microscope-pathD-visEm
30 mm to 60 mm Cage Plate Adapter, M4 Tap | LCP02/M | Thorlabs | 1 | £31.65 | £31.65
60 mm Cage System Translating Lens Mount for Ø2" Optics | CXY2 | Thorlabs | 1 | £157.90 | £157.90
Right-Angle Kinematic Elliptical Mirror Mount | KCB1EC/M | Thorlabs | 1 | £156.05 | £156.05
1" Broadband Dielectric Elliptical Mirror, 400 - 750 nm | BBE1-E02 | Thorlabs | 1 | £76.10 | £76.10
Tube Lens, f = 200 mm, ARC: 350 - 700 nm | TTL200-A | Thorlabs | 1 | £372.53 | £372.53
30 mm Cage System Removable Filter Holder for Ø1" Optics | CFH2/M | Thorlabs | 1 | £86.84 | £86.84
Bertrand-lens
30 mm Cage System Removable Filter Holder for Ø1" Optics | CFH2/M | Thorlabs | 1 | £86.84 | £86.84
f = 50 mm, Ø1" Achromatic Doublet, ARC: 400 - 700 nm | AC254-050-A | Thorlabs | 1 | £60.87 | £60.87
Astig-lens
30 mm Cage System Removable Filter Holder for Ø1" Optics | CFH2/M | Thorlabs | 1 | £86.84 | £86.84
f = 1000.0 mm, Ø1", N-BK7 Mounted Plano-Convex Round Cyl Lens | LJ1516RM-A | Thorlabs | 1 | £96.58 | £96.58
cam-emission-interface
30 mm Cage Plate | CP33/M | Thorlabs | 1 | £12.67 | £12.67
C-Mount Extension Tube, 10 mm Long | CML10 | Thorlabs | 1 | £13.45 | £13.45
camera-and-mount
Zyla 4.2 Plus Camera-link | ZYLA-4.2P-CL10 | Andor | 1 | £12650.00 | £12650.00
20 - Camera mount | - | 3D printed | 1 | £0.00 | £0.00
1/4-20 UNC - 15mm cap screw |  | PB Film & Technik - Amazon | 4 |  | £0.00
mounting-optomech
30 mm to 60 mm Cage Plate Adapter, M4 Tap | LCP02/M | Thorlabs | 1 | £31.65 | £31.65
Cage Assembly Rod, 4" Long | ER4 | Thorlabs | 2 | £5.48 | £10.96
Cage Assembly Rod, 3" Long | ER3 | Thorlabs | 4 | £5.10 | £20.40
focalPathEnclosure
focalPathLid | - | 3D printed | 1 | £0.00 | £0.00
focalEnclosure-body | - | 3D printed | 1 | £0.00 | £0.00
4-40 Stainless Steel Cap Screw, 1/4" Long, 50 Pack | SH4S025 | Thorlabs | 1 | £6.01 | £6.01
M3 screws, 20mm |  |  |  |  | £0.00
Ø12.7 mm Pedestal Post Holder | PH30E/M | Thorlabs | 1 | £18.66 | £18.66
Ø12.7 mm Optical Post, L = 40 mm | TR40/M | Thorlabs | 1 | £3.84 | £3.84
microscope-pathC-excitation
2d-galvo-in-housing
2D Large Beam (10 mm) Diameter Galvo System | GVS212/M | Thorlabs | 1 | £2606.01 | £2606.01
30 mm Cage Adapter for 10 mm Galvo System | GCM012/M | Thorlabs | 1 | £149.33 | £149.33
KCB2EC_M-with-mirror
Right-Angle Kinematic Elliptical Mirror Mount | KCB2EC/M | Thorlabs | 1 | £183.01 | £183.01
2" Broadband Dielectric Elliptical Mirror, 400 - 750 nm | BBE2-E02 | Thorlabs | 1 | £148.92 | £148.92
CXY1-with-200mmTubeLens
30 mm Cage System, XY Translating Lens Mount for Ø1" Optics | CXY1 | Thorlabs | 1 | £140.40 | £140.40
f = 200.0 mm, Ø1" Achromatic Doublet, ARC: 400 - 1100 nm | AC254-200-AB | Thorlabs | 1 | £77.25 | £77.25
mounting-optomech
Cage Assembly Rod, 6" Long | ER6 | Thorlabs | 4 | £6.68 | £26.72
SM1 Lens Tube | SM1L40 | Thorlabs | 1 | £35.46 | £35.46
30 mm Cage Plate | CP33/M | Thorlabs | 2 | £12.67 | £25.34
30 mm Cage Plate | CP33/M | Thorlabs | 1 | £12.67 | £12.67
Ø12.7 mm Optical Post, L = 100 mm | TR100/M | Thorlabs | 1 | £4.54 | £4.54
Ø12.7 mm Post Holder | PH50/M | Thorlabs | 1 | £5.95 | £5.95
1"post-75mm
Clamping Fork for Ø1.5" Pedestal Post | PF175B | Thorlabs | 1 | £12.75 | £12.75
Ø25.0 mm Pillar Post, L = 75 mm | RS75/M | Thorlabs | 1 | £19.48 | £19.48
Ø25 mm Post Holder, L = 50 mm | RSH2/M | Thorlabs | 1 | £24.96 | £24.96
1"post-50mm
Ø25 mm Post Holder, L = 50 mm | RSHT2/M | Thorlabs | 1 | £24.96 | £24.96
Ø25.0 mm Pillar Post, L = 50 mm | RS50/M | Thorlabs | 1 | £17.85 | £17.85
Mounting Base, 50 mm x 75 mm x 10 mm | BA2/M | Thorlabs | 1 | £5.64 | £5.64
mirror-galvo-spacer
Cage Assembly Rod, 2" Long | ER2 | Thorlabs | 4 | £4.71 | £18.84
Cage Assembly Rod, 1" Long | ER1 | Thorlabs | 4 | £3.90 | £15.60
30 mm to 60 mm Cage Plate Adapter | LCP02/M | Thorlabs | 1 | £31.65 | £31.65
SM2 Lens Tube, 3" Thread Depth | SM2L30 | Thorlabs | 1 | £28.57 | £28.57
Ø2" UVFS Wedged Vacuum Window, AR Coating: 350 - 700 nm | WW42012 | Thorlabs | 1 | £131.29 | £131.29
Galvo control bits
1m galvo extension cable | PAA634/SPL-S6 | Thorlabs | 2 | £60.00 | £120.00 | Special Order (available on request)
1D or 2D Galvo System Linear Power Supply | GPS011-EC | Thorlabs | 1 | £392.53 | £392.53
Galvo Driver Card Cover | GCE001 | Thorlabs | 2 | £46.46 | £92.92
microscope-pathB-autofocus-crisp (Focus Shifter)
CRISP-5 ASSEMBLY | DASI/CRISP-940 | ASI | 1 | £7206.93 | £7206.93
zoom-tube-lens
SM1 Zoom Housing for Ø1" Optics | SM1NR1 | Thorlabs | 1 | £161.51 | £161.51
N-BK7 Best Form Lens, Ø1", f = 100 mm, ARC: 650-1050 nm | LBF254-100-B | Thorlabs | 1 | £42.81 | £42.81
mounting-optomech
30 mm to 60 mm Cage Plate Adapter, M4 Tap | LCP02/M | Thorlabs | 2 | £31.65 | £63.30
Cage Assembly Rod, 6" Long | ER6 | Thorlabs | 4 | £6.68 | £26.72
60 mm Cage Plate | LCP01/M | Thorlabs | 1 | £30.84 | £30.84
Adapter with External C-Mount Threads and External SM2 Threads | SM2A55 | Thorlabs | 1 | £21.71 | £21.71
support-post
Ø12.7 mm Pedestal Post Holder, L=104.7 mm | PH100E/M | Thorlabs | 1 | £20.30 | £20.30
Clamping Fork | CF125C/M | Thorlabs | 1 | £8.77 | £8.77
Ø12.7 mm Optical Post, L = 150 mm | TR150/M | Thorlabs | 1 | £5.50 | £5.50
motorMountingBits
Zoom-housing-custom-pulley | - | 3D printed | 1 | £0.00 | £0.00
RS PRO, Timing Belt, 115 Teeth, 233.68mm Length X 6mm Width | 778-5073 | RS | 1 | £2.75 | £2.75
Motor-cage-coupler | - | 3D printed | 1 | £0.00 | £0.00
motor
pulley-RS-778-4714 | 778-4714 | RS | 1 | £6.18 | £6.18
RS PRO Hybrid Stepper Stepper Motor, 12 V, 5mm Shaft Diameter | 180-5279 | RS | 1 | £23.13 | £23.13
Focus-shifter electronics
Arduino Uno | 715-4081 | RS | 1 | £17.00 | £17.00
Adafruit Motor/Stepper/Servo Shield for Arduino v2 Kit - v2.3 | 1438 | Adafruit/ https://thepihut.com | 1 | £18.50 | £18.50
PCB headers | 251-8351 | RS | 1 | £0.75 | £0.75
7.2W Plug In Power Supply | 735-0747 | RS | 1 | £11.85 | £11.85
Spade Crimp Connectors (100 Pack) | 534-339 | RS | 1 | £9.70 | £9.70
Push Button | SW05762 | CPC Farnell | 1 | £1.72 | £1.72
DPDT Rocker switch | 907-7071 | RS | 1 | £7.60 | £7.60
Arduino enclosure | - | 3D printed | 1 | £0.00 | £0.00
Serial Cable Assembly 3m Male to Female, DB9 to DB9 | 777-637 | RS | 1 | £11.52 | £11.52
RS PRO Panel Mount, 9 Pin D-sub Connector Socket, Shell Size E, Solder Cup (10 Pack) | 544-3749 | RS | 1 | £3.10 | £3.10
RS PRO Panel Mount, 9 Pin D-sub Connector Plug, Shell Size E, Solder Cup (10 Pack) | 544-3727 | RS | 1 | £3.10 | £3.10
RS PRO Female UNC 4-40 Screwlock Suitable For D Connector for use with D Connector (10 Pack) | 453-886 | RS | 1 | £6.42 | £6.42
Jumper wires | 505-3396 | RS | 1 | £4.59 | £4.59
Black hookup wire | 884-0837 | RS | 1 | £6.27 | £6.27
Red hookup wire | 874-0374 | RS | 1 | £6.27 | £6.27
microscope-pathA-imageAutofocus (Imlock)
pathA-optics
Blackfly BFS-U3-51S5 | BFS-U3-51S5M-C | FLIR | 1 | £1013.00 | £1013.00
Coarse ±1 mm XY Slip Plate Positioner | SPT1/M | Thorlabs | 1 | £49.91 | £49.91
Best Form Lens, Ø1", f = 100 mm, ARC: 650-1050 nm | LBF254-100-B | Thorlabs | 1 | £42.81 | £42.81
SM1 (1.035"-40) Coupler | SM1T2 | Thorlabs | 1 | £16.16 | £16.16
SM1 Lens Tube | SM1L10 | Thorlabs | 1 | £11.01 | £11.01
SM1-Threaded 30 mm Cage Plate | CP33/M | Thorlabs | 1 | £12.67 | £12.67
Cage Assembly Rod, 3" Long | ER3 | Thorlabs | 4 | £5.10 | £20.40
Extension Tube, Internal SM1 Threading of 0.50" Depth, External C-Mount Threading | CM1L05 | Thorlabs | 1 | £14.57 | £14.57
pathA-lightCover | - | 3D printed | 1 | £0.00 | £0.00
Controlers
Tiger Controler (For Stage) | DASI/TG8_BASIC | ASI | 1 | £3573.35 | £3573.35
LED Driver | DASI/TGLED | ASI | 1 | £521.95 | £521.95
XY Stage Encoder | DASI/LE-XY-130mm | ASI | 1 | £4015.00 | £4015.00
Filters
Multiband Dichroic | ZT405/488/561/640rpcv2 | Chroma | 1 | £401.00 | £401.00
640nm Dichroic | ZT-640rdc | Chroma | 1 | £219.00 | £219.00
561nm Dichroic | ZT-561rdc | Chroma | 1 | £219.00 | £219.00
810nm Dichroic | T810lpxr | Chroma | 1 | £164.00 | £164.00
500nm Emission | ET-500lp | Chroma | 1 | £237.00 | £237.00
525nm Emission | ET-525/50m | Chroma | 1 | £237.00 | £237.00
Multiband Emission | ZET-405/488/561/640mv2 | Chroma | 1 | £456.00 | £456.00
595nm Emission | ET595/44m | Chroma | 1 | £237.00 | £237.00
706nm Emission | ET706/95m | Chroma | 1 | £237.00 | £237.00
900nm Dichroic | DMLP900R | Thorlabs | 1 | £298.67 | £298.67
850nm Bandpass | FBH850-40 | Thorlabs | 1 | £112.50 | £112.50
Total |  |  |  |  | £80318.14

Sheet: Focus Shifter
Focus Shifter (Also incuded in Main Body)
Part name | Part number | Supplier | Quantity | Price | Subtotal | Notes
CRISP-5 ASSEMBLY | DASI/CRISP-940 | ASI | 1 | £7206.93 | £7206.93
zoom-tube-lens
SM1 Zoom Housing for Ø1" Optics | SM1NR1 | Thorlabs | 1 | £161.51 | £161.51
N-BK7 Best Form Lens, Ø1", f = 100 mm, ARC: 650-1050 nm | LBF254-100-B | Thorlabs | 1 | £42.81 | £42.81
mounting-optomech
30 mm to 60 mm Cage Plate Adapter, M4 Tap | LCP02/M | Thorlabs | 2 | £31.65 | £63.30
Cage Assembly Rod, 6" Long | ER6 | Thorlabs | 4 | £6.68 | £26.72
60 mm Cage Plate | LCP01/M | Thorlabs | 1 | £30.84 | £30.84
Adapter with External C-Mount Threads and External SM2 Threads | SM2A55 | Thorlabs | 1 | £21.71 | £21.71
support-post
Ø12.7 mm Pedestal Post Holder, L=104.7 mm | PH100E/M | Thorlabs | 1 | £20.30 | £20.30
Clamping Fork | CF125C/M | Thorlabs | 1 | £8.77 | £8.77
Ø12.7 mm Optical Post, L = 150 mm | TR150/M | Thorlabs | 1 | £5.50 | £5.50
motorMountingBits
Zoom-housing-custom-pulley | - | 3D printed | 1 | £0.00 | £0.00
RS PRO, Timing Belt, 115 Teeth, 233.68mm Length X 6mm Width | 778-5073 | RS | 1 | £2.75 | £2.75
Motor-cage-coupler | - | 3D printed | 1 | £0.00 | £0.00
motor
pulley-RS-778-4714 | 778-4714 | RS | 1 | £6.18 | £6.18
RS PRO Hybrid Stepper Stepper Motor, 12 V, 5mm Shaft Diameter | 180-5279 | RS | 1 | £23.13 | £23.13
Focus-shifter electronics
Arduino Uno | 715-4081 | RS | 1 | £17.00 | £17.00
Adafruit Motor/Stepper/Servo Shield for Arduino v2 Kit - v2.3 | 1438 | Adafruit/ https://thepihut.com | 1 | £18.50 | £18.50
PCB headers | 251-8351 | RS |  | £0.75 | £0.00
7.2W Plug In Power Supply | 735-0747 | RS | 1 | £11.85 | £11.85
Spade Crimp Connectors (100 Pack) | 534-339 | RS | 1 | £9.70 | £9.70
Push Button | SW05762 | CPC Farnell | 1 | £1.72 | £1.72
DPDT Rocker switch | 907-7071 | RS | 1 | £7.60 | £7.60
Arduino enclosure | - | 3D printed | 1 | £0.00 | £0.00
Serial Cable Assembly 3m Male to Female, DB9 to DB9 | 777-637 | RS | 1 | £11.52 | £11.52
RS PRO Panel Mount, 9 Pin D-sub Connector Socket, Shell Size E, Solder Cup (10 Pack) | 544-3749 | RS | 1 | £3.10 | £3.10
RS PRO Panel Mount, 9 Pin D-sub Connector Plug, Shell Size E, Solder Cup (10 Pack) | 544-3727 | RS | 1 | £3.10 | £3.10
RS PRO Female UNC 4-40 Screwlock Suitable For D Connector for use with D Connector (10 Pack) | 453-886 | RS | 1 | £6.42 | £6.42
Jumper wires | 505-3396 | RS | 1 | £4.59 | £4.59
Black hookup wire | 884-0837 | RS | 1 | £6.27 | £6.27
Red hookup wire | 874-0374 | RS | 1 | £6.27 | £6.27
Total |  |  |  |  | £7728.09

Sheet: ImLock
ImLock (Also in Main Body)
Part name | Part number | Supplier | Quantity | Price | Subtotal | Notes
Blackfly BFS-U3-51S5 | BFS-U3-51S5M-C | FLIR | 1 | £1013.00 | £1013.00
Coarse ±1 mm XY Slip Plate Positioner | SPT1/M | Thorlabs | 1 | £49.91 | £49.91
Best Form Lens, Ø1", f = 100 mm, ARC: 650-1050 nm | LBF254-100-B | Thorlabs | 1 | £42.81 | £42.81
SM1 (1.035"-40) Coupler | SM1T2 | Thorlabs | 1 | £16.16 | £16.16
SM1 Lens Tube | SM1L10 | Thorlabs | 1 | £11.01 | £11.01
SM1-Threaded 30 mm Cage Plate | CP33/M | Thorlabs | 1 | £12.67 | £12.67
Cage Assembly Rod, 3" Long | ER3 | Thorlabs | 4 | £5.10 | £20.40
Extension Tube, Internal SM1 Threading of 0.50" Depth, External C-Mount Threading | CM1L05 | Thorlabs | 1 | £14.57 | £14.57
pathA-lightCover | - | 3D printed | 1 | £0.00 | £0.00
Total |  |  |  |  | £1180.53

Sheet: Other Hardware
Parts List
 | Part number | Supplier | Quantity | Price | Subtotal
Hardware Triggering
TriggerScope 3B | - | Advanced Research Consulting | 1 | £949.00 | £949.00
8" SMA-BNC, Male-Male Cable | 885-8172 | RS | 2 | £10.34 | £20.68
Male SMA to Male SMA RG-58 Coaxial Cable, 50 Ω, | 885-7817 | RS | 3 | £15.22 | £45.66
RS PRO Black Female SMA to Unterminated Coaxial Cable, 50 Ω | 794-2857 | RS | 2 | £5.01 | £10.02
TE Connectivity 50 Ω, Male SMB to Male SMB Coaxial Cable Assembly, 1m length, RG174 cable type | 409-8102 | RS | 2 | £14.25 | £28.50
50 Ohm SMA Plug to SMB Plug Adaptor | CN20671 | Farnell | 2 | £4.01 | £8.02
25 Way Panel Mount D-sub Connector Socket, 2.76mm Pitch | 542-7876 | RS | 1 | £1.52 | £1.52
Optical Table
1m x 2m x 210mm Sealed Holes Metric Optical Table | T1020P | Thorlabs | 1 | £2812.14 | £2812.14
Air Compressor | PTA513 | Thorlabs | 1 | £468.18 | £468.18
Compressor Oil | PTA1006 | Thorlabs | 1 | £35.19 | £35.19
Table Frame 1m x 2m, Active, 700mm | TF1020A7 | Thorlabs | 1 | £2815.97 | £2815.97
DAQ board
PCIe-6321, X Series DAQ (16 AI, 24 DIO, 2AO) | 781044-01 | National Instruments | 1 | £630.00 | £630.00
SBC-68A Noise Rejecting, Shielded I/O Connector Block | 782536-01 | National Instruments | 1 | £330.00 | £330.00
SHC68-68-EMP Shielded Cable, 68-D-Type to 68 VHDCI Offset, 2m | 192061-02 | National Instruments | 1 | £141.00 | £141.00
Graphics Card
MSI S10226923 8GB Nvidia GeForce RTX 2070 ARMOR FH GDDR6 DP/HDMI TURING VR 4K PCI Express Graphics Card |  |  | 2 | £496.29 | £992.58
Total |  |  |  |  | £9288.46

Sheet: Incubator box
 | Supplier | Part number | Price | Quantity | Subtotal
CAD Design
Custom box components | - | - | £1250.00 | 1 | £1250.00
Front
Incubation-Chamber-Front-Panel | - | - | - | 1
Incubation-Chamber-Front-Window | - | - | - | 1
Incubation-Chamber-Front-Window-Cover | - | - | - | 1
Incubation-Chamber-Front-Window-Cover-Mount | - | - | - | 2
Incubation-Chamber-Front-Middle-Door | - | - | - | 1
Incubation-Chamber-Front-Middle-Door-Mount1 | - | - | - | 1
Incubation-Chamber-Front-Middle-Door-Mount2 | - | - | - | 2
Incubation-Chamber-Front-Middle-Door-Mount3 | - | - | - | 1
Incubation-Chamber-Front-Bottom-Door | - | - | - | 1
Incubation-Chamber-Front-Bottom-Door-Mount1 | - | - | - | 1
Incubation-Chamber-Front-Bottom-Door-Mount2 | - | - | - | 1
Incubation-Chamber-Front-Bottom-Door-Mount3 | - | - | - | 1
Incubation-Chamber-Front-Bottom-Door-Mount4 | - | - | - | 1
Incubation-Chamber-Door-Latch | - | - | - | 2
Hinge (2 pack) | RS | 268-2086 | £19.30 | 3 | £57.90
Left
Incubation-Chamber-Left-Panel | - | - | - | 1
Incubation-Chamber-Left-Camera-Port | - | - | - | 1
Incubation-Chamber-Left-Door | - | - | - | 1
Incubation-Chamber-Left-Door-Mount1 | - | - | - | 1
Incubation-Chamber-Left-Door-Mount2 | - | - | - | 1
Incubation-Chamber-Left-Door-Mount3 | - | - | - | 1
Incubation-Chamber-Left-Door-Mount4 | - | - | - | 1
Incubation-Chamber-Door-Latch | - | - | - | 1
Hinge (2 pack) | RS | 268-2086 | £19.30 | 1 | £19.30
Right
Incubation-Chamber-Right-Panel | - | - | - | 1
Incubation-Chamber-Right-Crisp-Hatch | - | - | - | 1
Incubation-Chamber-Right-Door | - | - | - | 1
Incubation-Chamber-Right-Door-Mount1 | - | - | - | 1
Incubation-Chamber-Right-Door-Mount2 | - | - | - | 2
Incubation-Chamber-Right-Door-Mount3 | - | - | - | 1
Incubation-Chamber-Door-Latch | - | - | - | 1
Hinge (2 pack) | RS | 268-2086 | £19.30 | 1 | £19.30
Back
Incubation-Chamber-Back-Panel | - | - | - | 1
Incubation-Chamber-Back-Excitation-Hatch | - | - | - | 1
Incubation-Chamber-Back-Access-Hatch | - | - | - | 1
Incubation-Chamber-Back-Top-Heater-Mount | - | - | - | 2
Incubation-Chamber-Back-Bottom-Heater-Mount | - | - | - | 2
Top
Incubation-Chamber-Top-Panel | - | - | - | 1
Incubation-Chamber-Top-Hatch | - | - | - | 1
Incubation-Chamber-Top-Back-Diffuser-Guide | - | - | - | 2
Incubation-Chamber-Top-Front-Diffuser-Guide | - | - | - | 2
Incubation-Chamber-Top-Diffuser-Mount | - | - | - | 4
General
M4 x 16mm Hex Socket Button Screw Black (100 pack) | RS | 281-243 | £10.66 | 2 | £21.32
10mm Threaded Hole M3 Ferrite Pot Magnet (2 Pack) | RS | 667-9977 | £2.38 | 2 | £4.76
M3 x 16mm Hex Socket Cap Screw Plain Stainless Steel (50 Pack) | RS | 187-1235 | £13.98 | 1 | £13.98
Neoprene
Foam Board
Heater Unit
Cube2 Air Heater | Life Imaging Services | 14130 | £5890.00 | 1 | £5890.00
Air Hose, 7.5, clear | Life Imaging Services | 10035 | £190.00 | 1 | £190.00
Flange for 2" Air Hose | Life Imaging Services | 10034 | £36.00 | 4 | £144.00
Diffuser Filters 500x300mm (4 Pack) | Life Imaging Services | 90051 | £25.00 | 1 | £25.00
Flange Extension, 70mm | Life Imaging Services | - | £30.00 | 2 | £60.00
Total |  |  |  |  | £7695.56

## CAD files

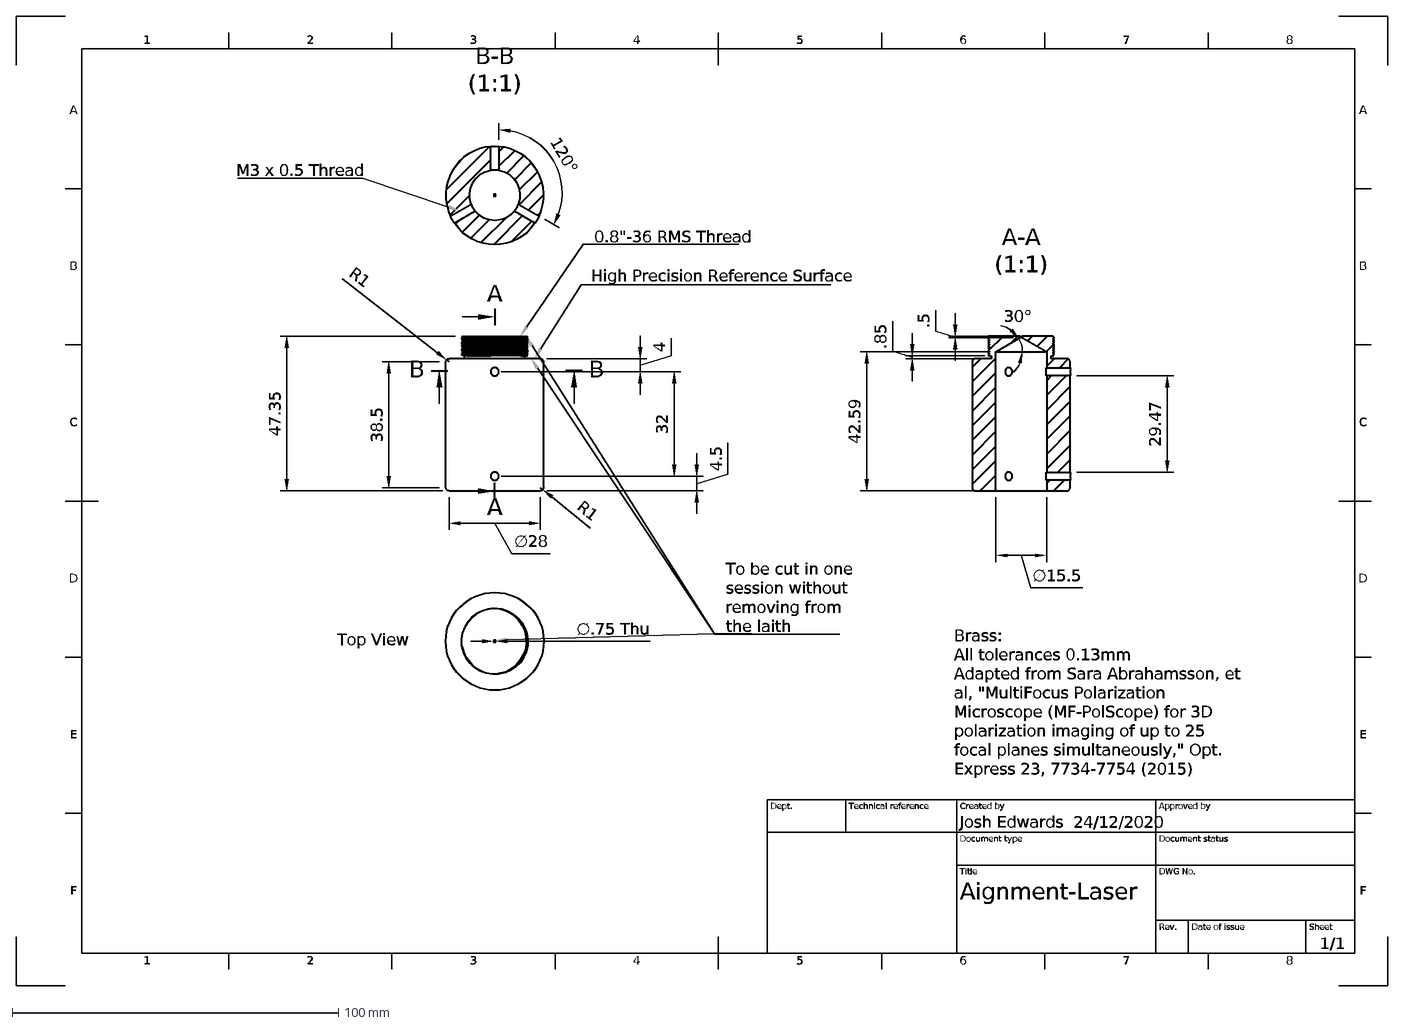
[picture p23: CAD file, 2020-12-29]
Alignment Laser/Aignment-Laser Drawing.dxf
1
A
2
3
4
5
6
7
8
B
C
D
E
F
24/12/2020
1/1
Aignment-Laser
Josh Edwards
Dept.
Technical reference
Created by
Approved by
Document type
Document status
Title
DWG No.
Rev.
Date of issue
Sheet
A-A (1:1)
29.47
38.5
47.35
B-B (1:1)
∅28
R1
120°
∅.75 Thu
Top View
42.59
∅15.5
30°
.85
32
4.5
.5
M3 x 0.5 Thread
High Precision Reference Surface
0.8"-36 RMS Thread
To be cut in one
session without
removing from
the laith
Brass: All tolerances 0.13mm Adapted from Sara Abrahamsson, et al, "MultiFocus Polarization Microscope (MF-PolScope) for 3D polarization imaging of up to 25 foc

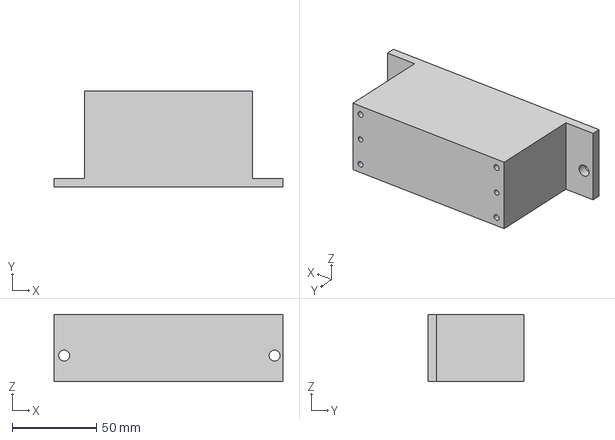
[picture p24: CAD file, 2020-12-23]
Excitation Module/Parts/Diode Laser Mount - Aluminium.step
136.0 x 57.2 x 40.0 mm

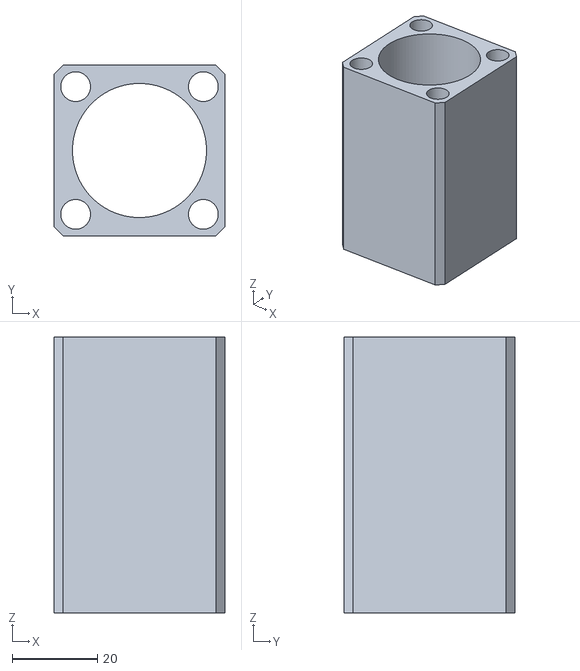
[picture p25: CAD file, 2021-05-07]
ImLock/Parts/ImLock-LightCover.stl
40.1 x 40.1 x 64.8

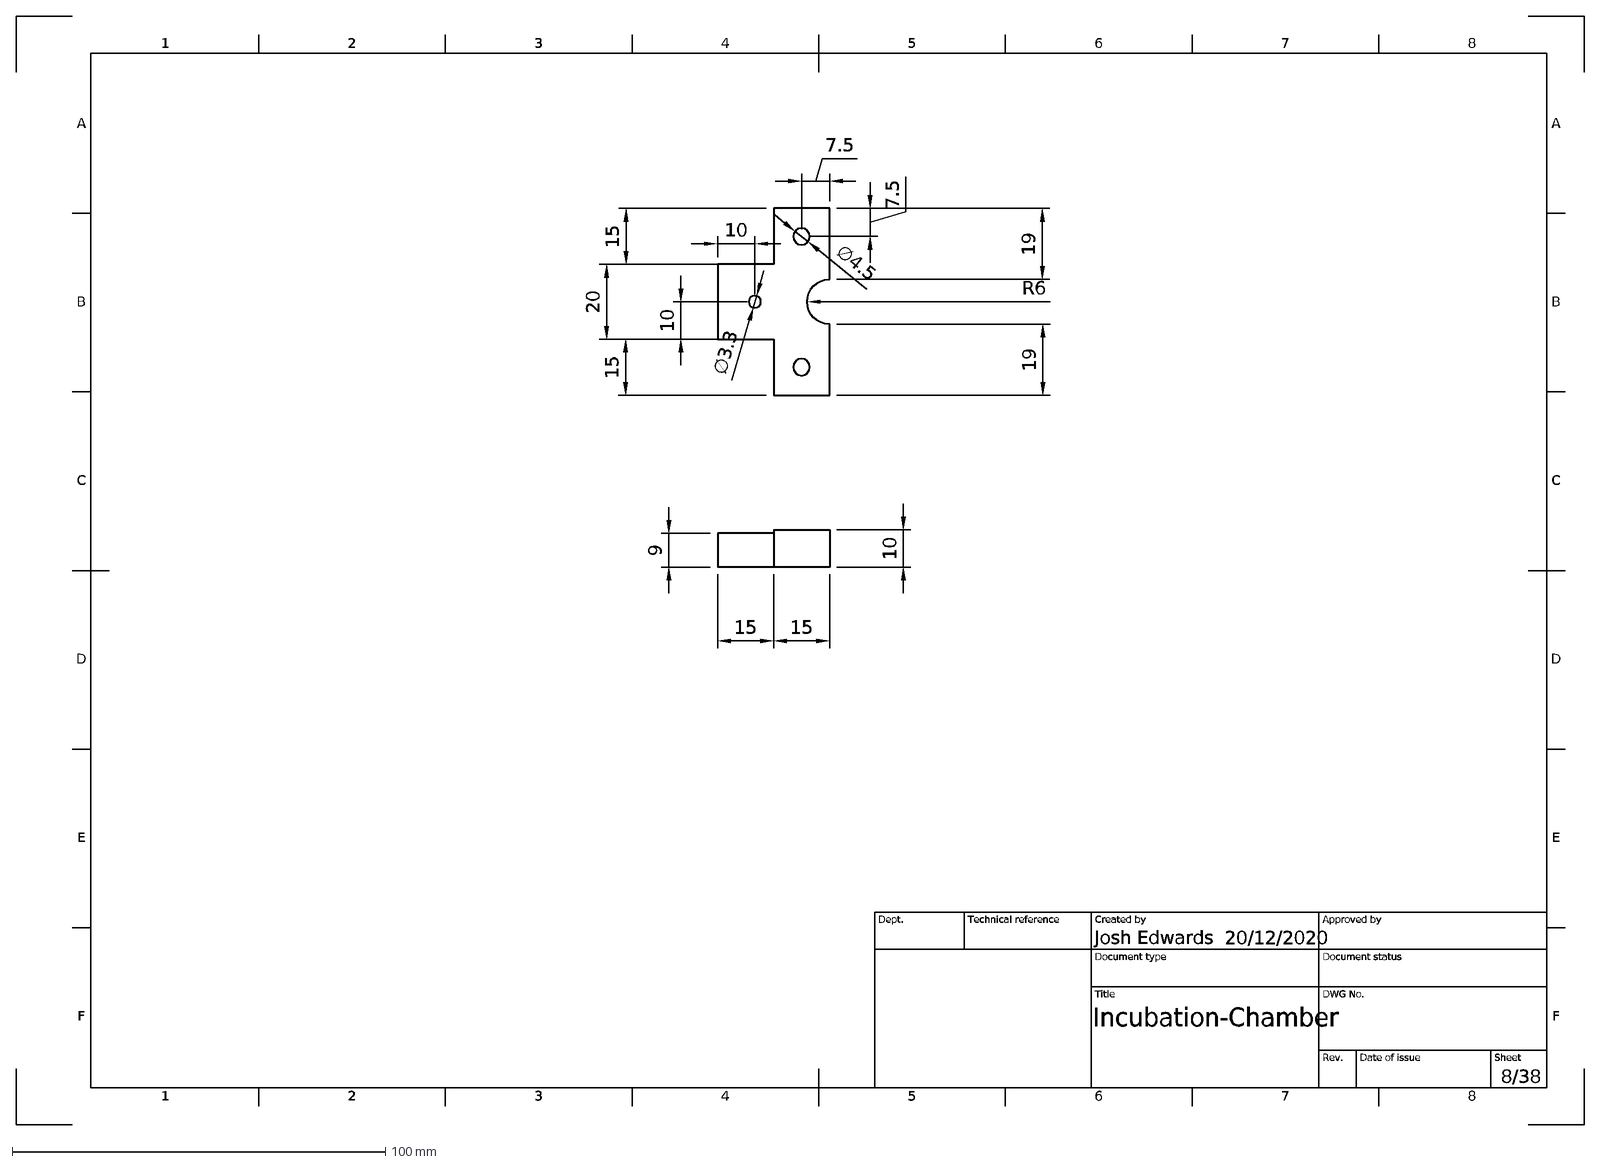
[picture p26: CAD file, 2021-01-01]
Incubation Box/Parts/Incubation-Chamber-Door-Latch.dxf
1
A
2
3
4
5
6
7
8
B
C
D
E
F
20/12/2020
8/38
Incubation-Chamber
Josh Edwards
Dept.
Technical reference
Created by
Approved by
Document type
Document status
Title
DWG No.
Rev.
Date of issue
Sheet
15
10
19
R6
20
∅3.3
7.5
∅4.5
9

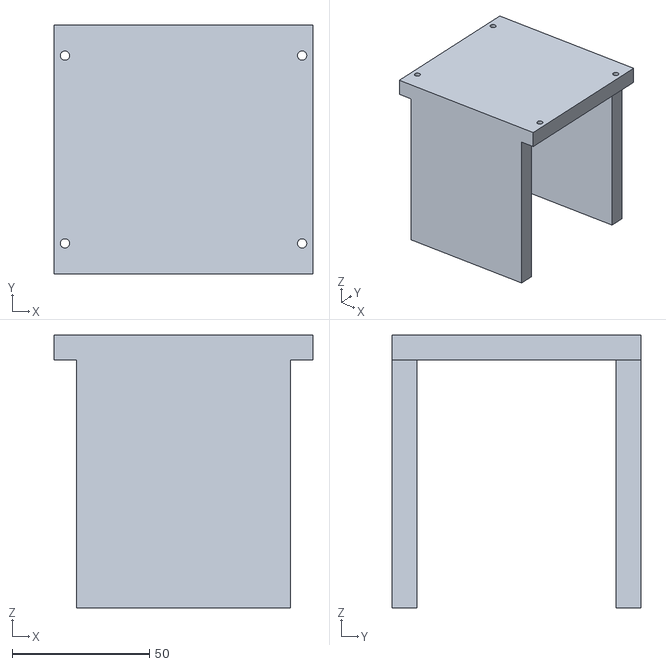
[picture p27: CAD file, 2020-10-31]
Main Body/Parts/Astig Box/Astig-Box-Lid.stl
94.4 x 90.6 x 99.4

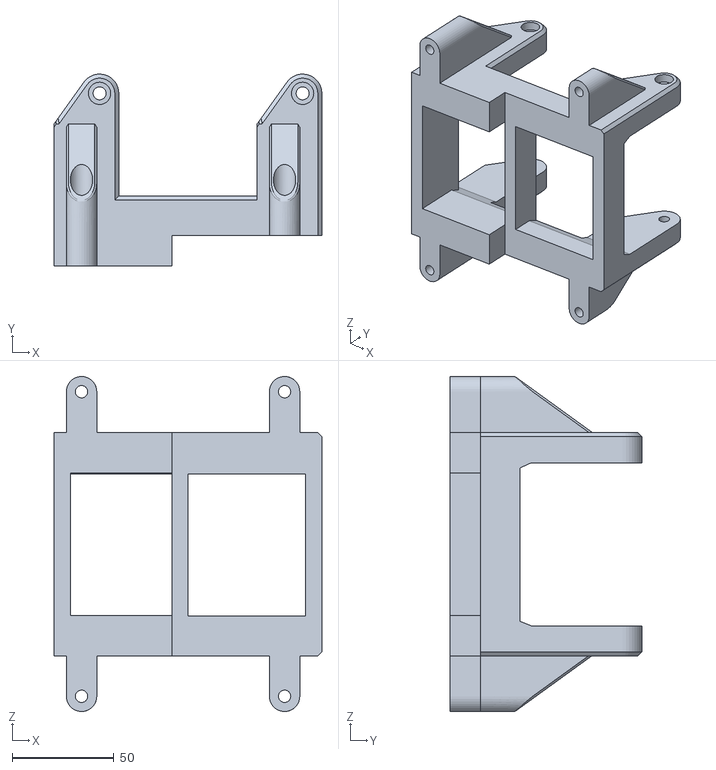
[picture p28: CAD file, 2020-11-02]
Main Body/Parts/Camera mount (Without Optosplit).stl
131.9 x 94.5 x 165.0

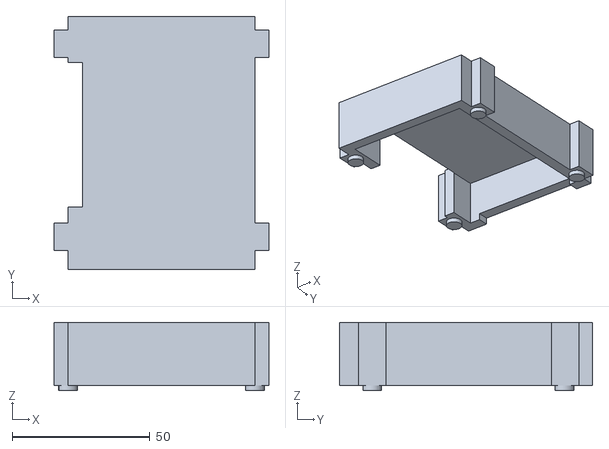
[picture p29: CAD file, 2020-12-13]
Main Body/Parts/Focus Shifter/Arduino Box/Arduino Box Top.stl
78.0 x 92.0 x 24.9

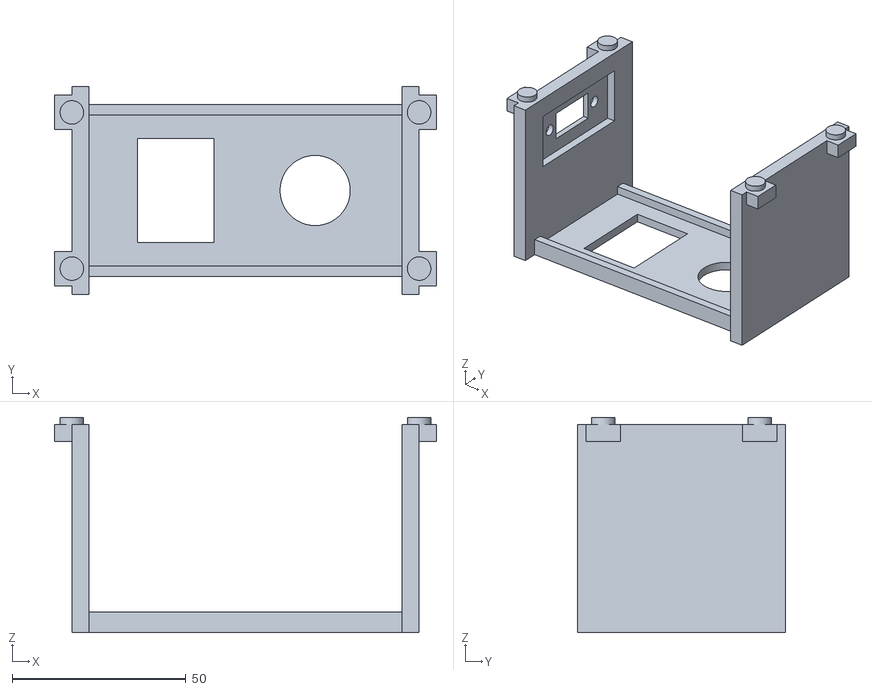
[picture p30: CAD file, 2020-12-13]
Main Body/Parts/Focus Shifter/Controller Box/Controller Box Top.stl
110.0 x 60.0 x 62.0

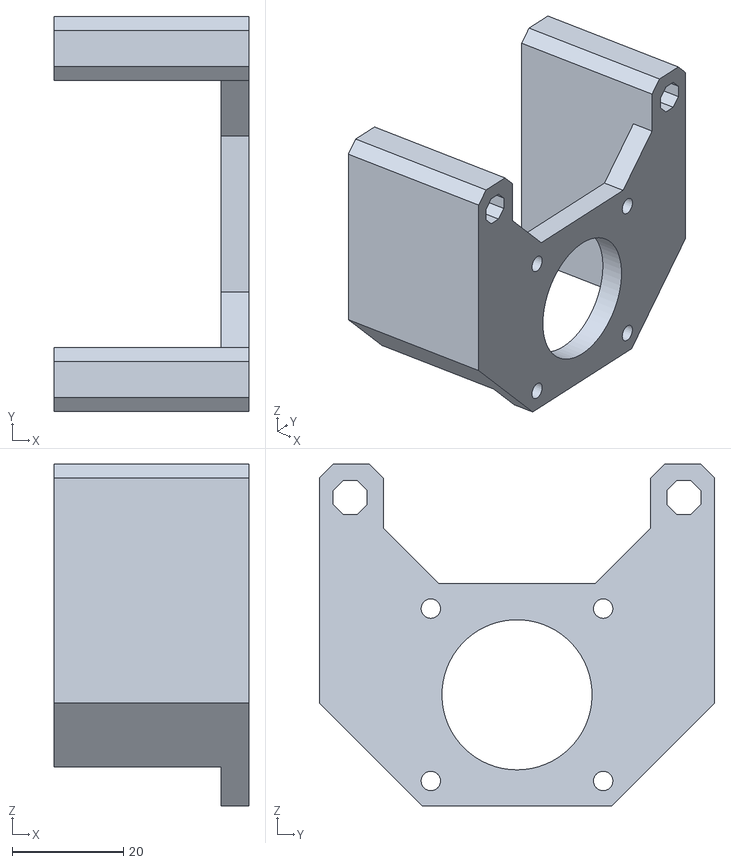
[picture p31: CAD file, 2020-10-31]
Main Body/Parts/Focus Shifter/Motor-cage-coupler.stl
35.0 x 71.1 x 61.5

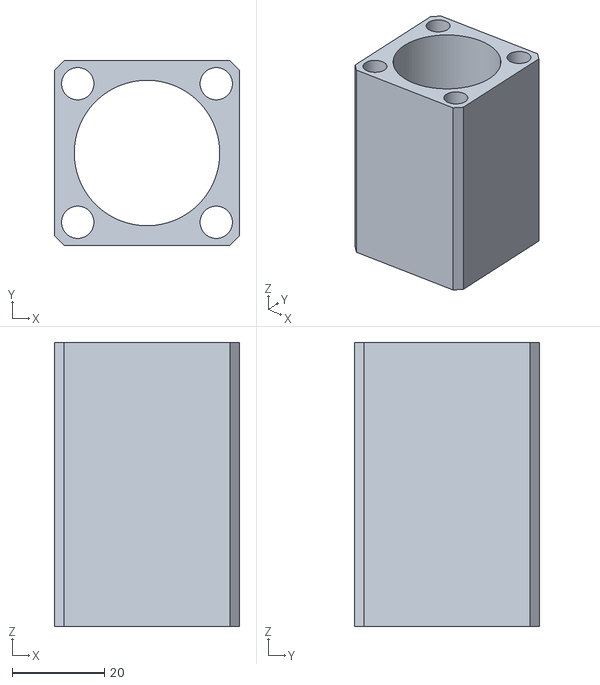
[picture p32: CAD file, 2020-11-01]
Main Body/Parts/Image Autofocus/Autofocus-Path-Cover.stl
40.1 x 40.1 x 61.5

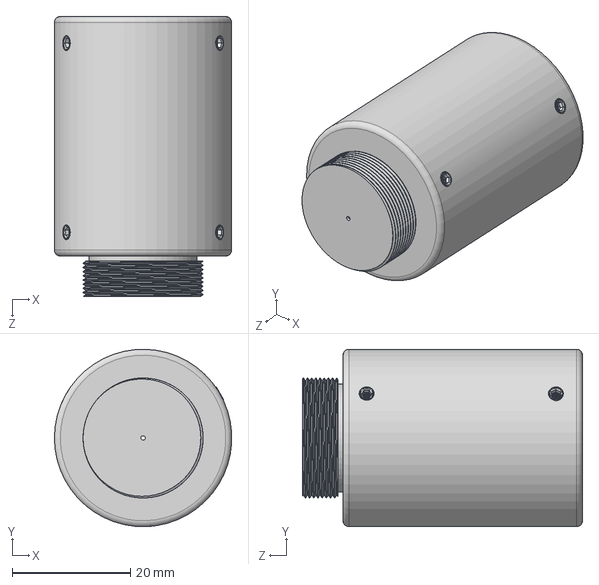
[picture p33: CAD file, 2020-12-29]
Alignment Laser/Aignment-Laser.step
30.0 x 30.0 x 47.4 mm
SS3M6-Solidworks x 6
Alignment Laser Housing

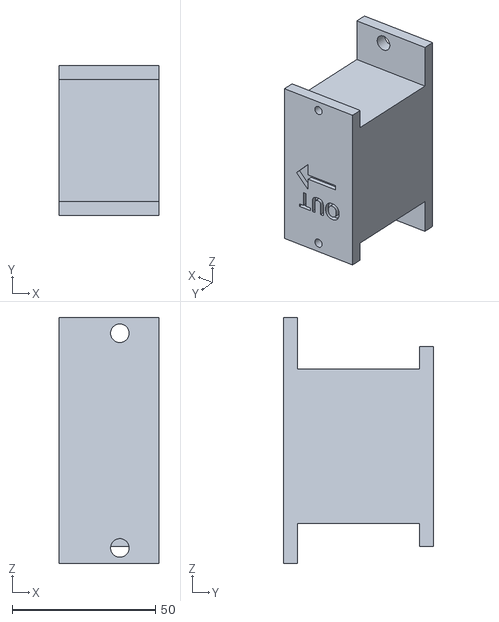
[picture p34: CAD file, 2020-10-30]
Excitation Module/Parts/AOTF Mount.stl
35.0 x 52.6 x 86.0

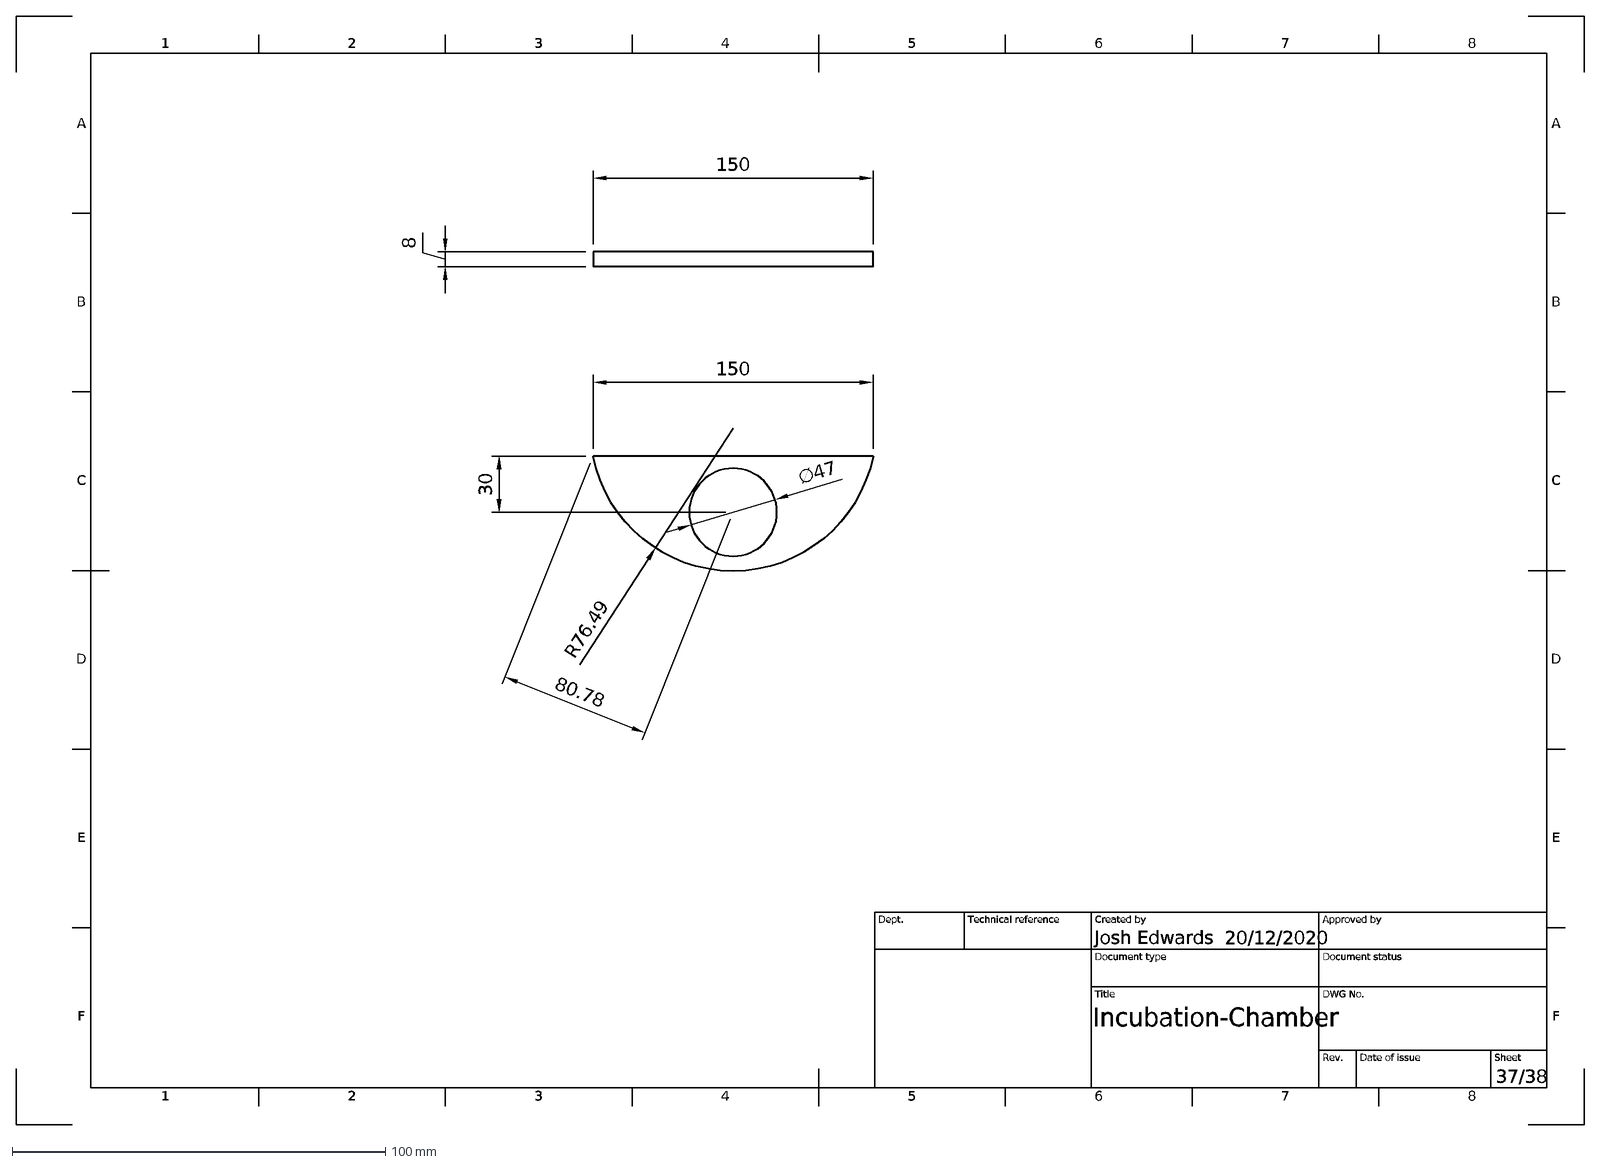
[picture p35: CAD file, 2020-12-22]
Incubation Box/Parts/Incubation-Chamber-Top-Back-Diffuser-Guide.dxf
1
A
2
3
4
5
6
7
8
B
C
D
E
F
20/12/2020
37/38
Incubation-Chamber
Josh Edwards
Dept.
Technical reference
Created by
Approved by
Document type
Document status
Title
DWG No.
Rev.
Date of issue
Sheet
150
R76.49
∅47
30
80.78

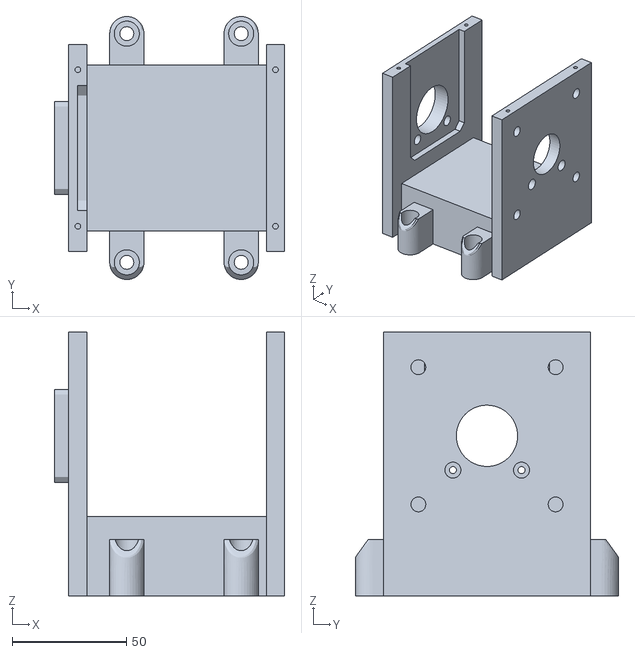
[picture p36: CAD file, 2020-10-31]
Main Body/Parts/Astig Box/Astig-Box-Body.stl
100.6 x 115.0 x 115.3

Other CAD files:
Main Body/Parts/Camera mount (With OptoSplit).stl
Main Body/Parts/Focus Shifter/Arduino Box/Arduino Box Bottom.stl
Main Body/Parts/Focus Shifter/Controller Box/Controller Box Bottom.stl
Excitation Module/Parts/Diode Laser Mount - 3D Print.stl
Excitation Module/Parts/Fiber Laser Mount - 3D Print.stl
Incubation Box/Parts/Incubation-Chamber-Back-Access-Hatch.dxf
Incubation Box/Parts/Incubation-Chamber-Back-Bottom-Heater-Mount.dxf
Incubation Box/Parts/Incubation-Chamber-Back-Excitation-Hatch.dxf
Incubation Box/Parts/Incubation-Chamber-Back-Panel.dxf
Incubation Box/Parts/Incubation-Chamber-Back-Top-Heater-Mount.dxf
Incubation Box/Parts/Incubation-Chamber-Front-Bottom-Door-Mount1.dxf
Incubation Box/Parts/Incubation-Chamber-Front-Bottom-Door-Mount2.dxf
Incubation Box/Parts/Incubation-Chamber-Front-Bottom-Door-Mount3.dxf
Incubation Box/Parts/Incubation-Chamber-Front-Bottom-Door-Mount4.dxf
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

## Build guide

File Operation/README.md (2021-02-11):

# Operation

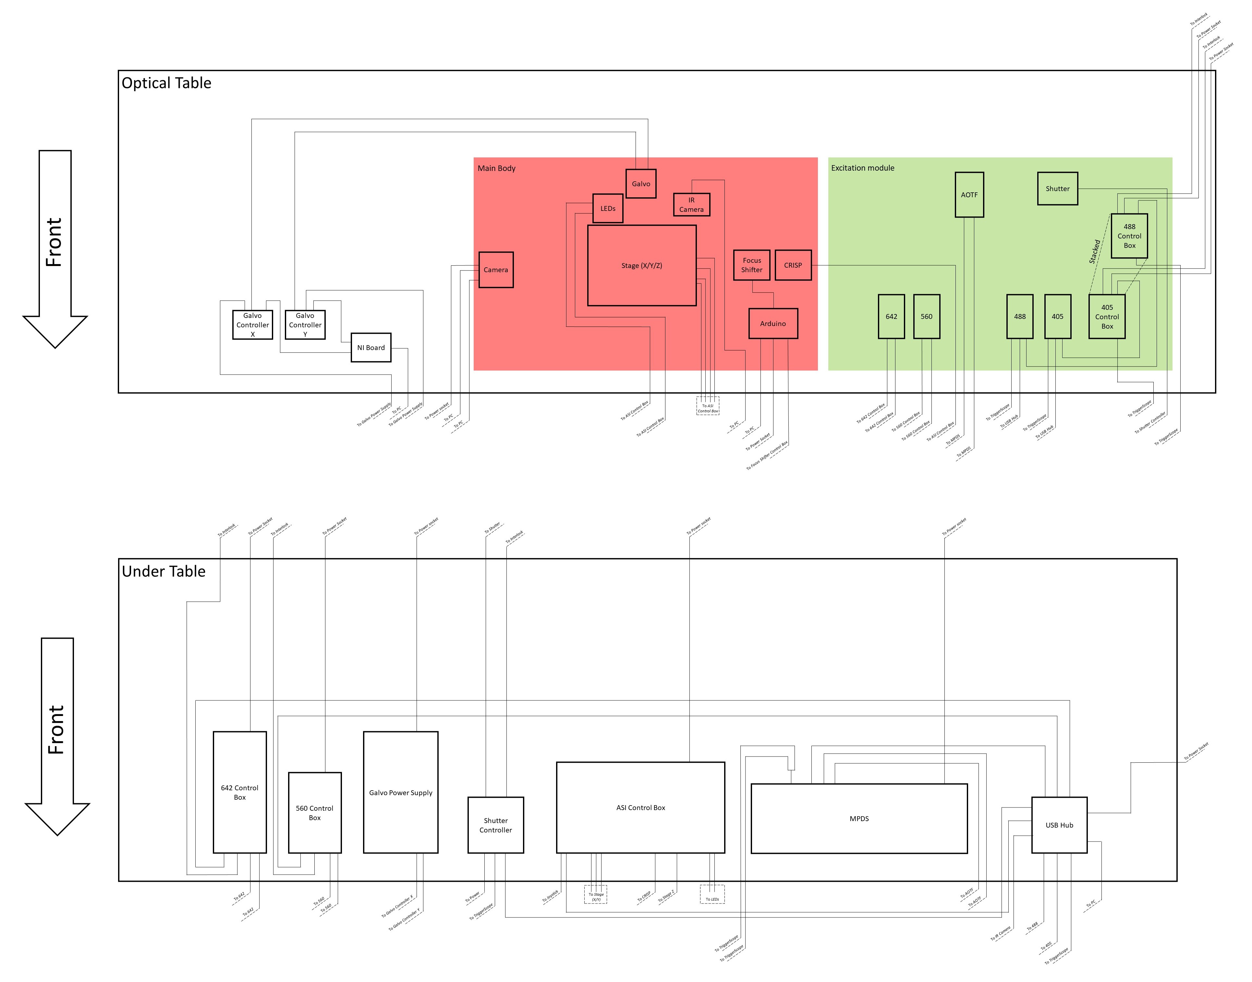
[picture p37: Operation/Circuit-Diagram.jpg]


## Control Software

Our set up uses <a href="https://micro-manager.org/wiki/Download_Micro-Manager_Latest_Release">Micromanager 2.0.0-gamma1_20210124</a>

The Triggerscope uses Micromanager specific firmware from <a href="https://github.com/micro-manager/TriggerScopeMM/">here</a>

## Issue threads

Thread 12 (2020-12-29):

Sort Box temperature stability

Joshedwards222, 2020-12-29:

Closed 2021-06-01.

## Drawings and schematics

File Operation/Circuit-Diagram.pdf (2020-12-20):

# Optical Table

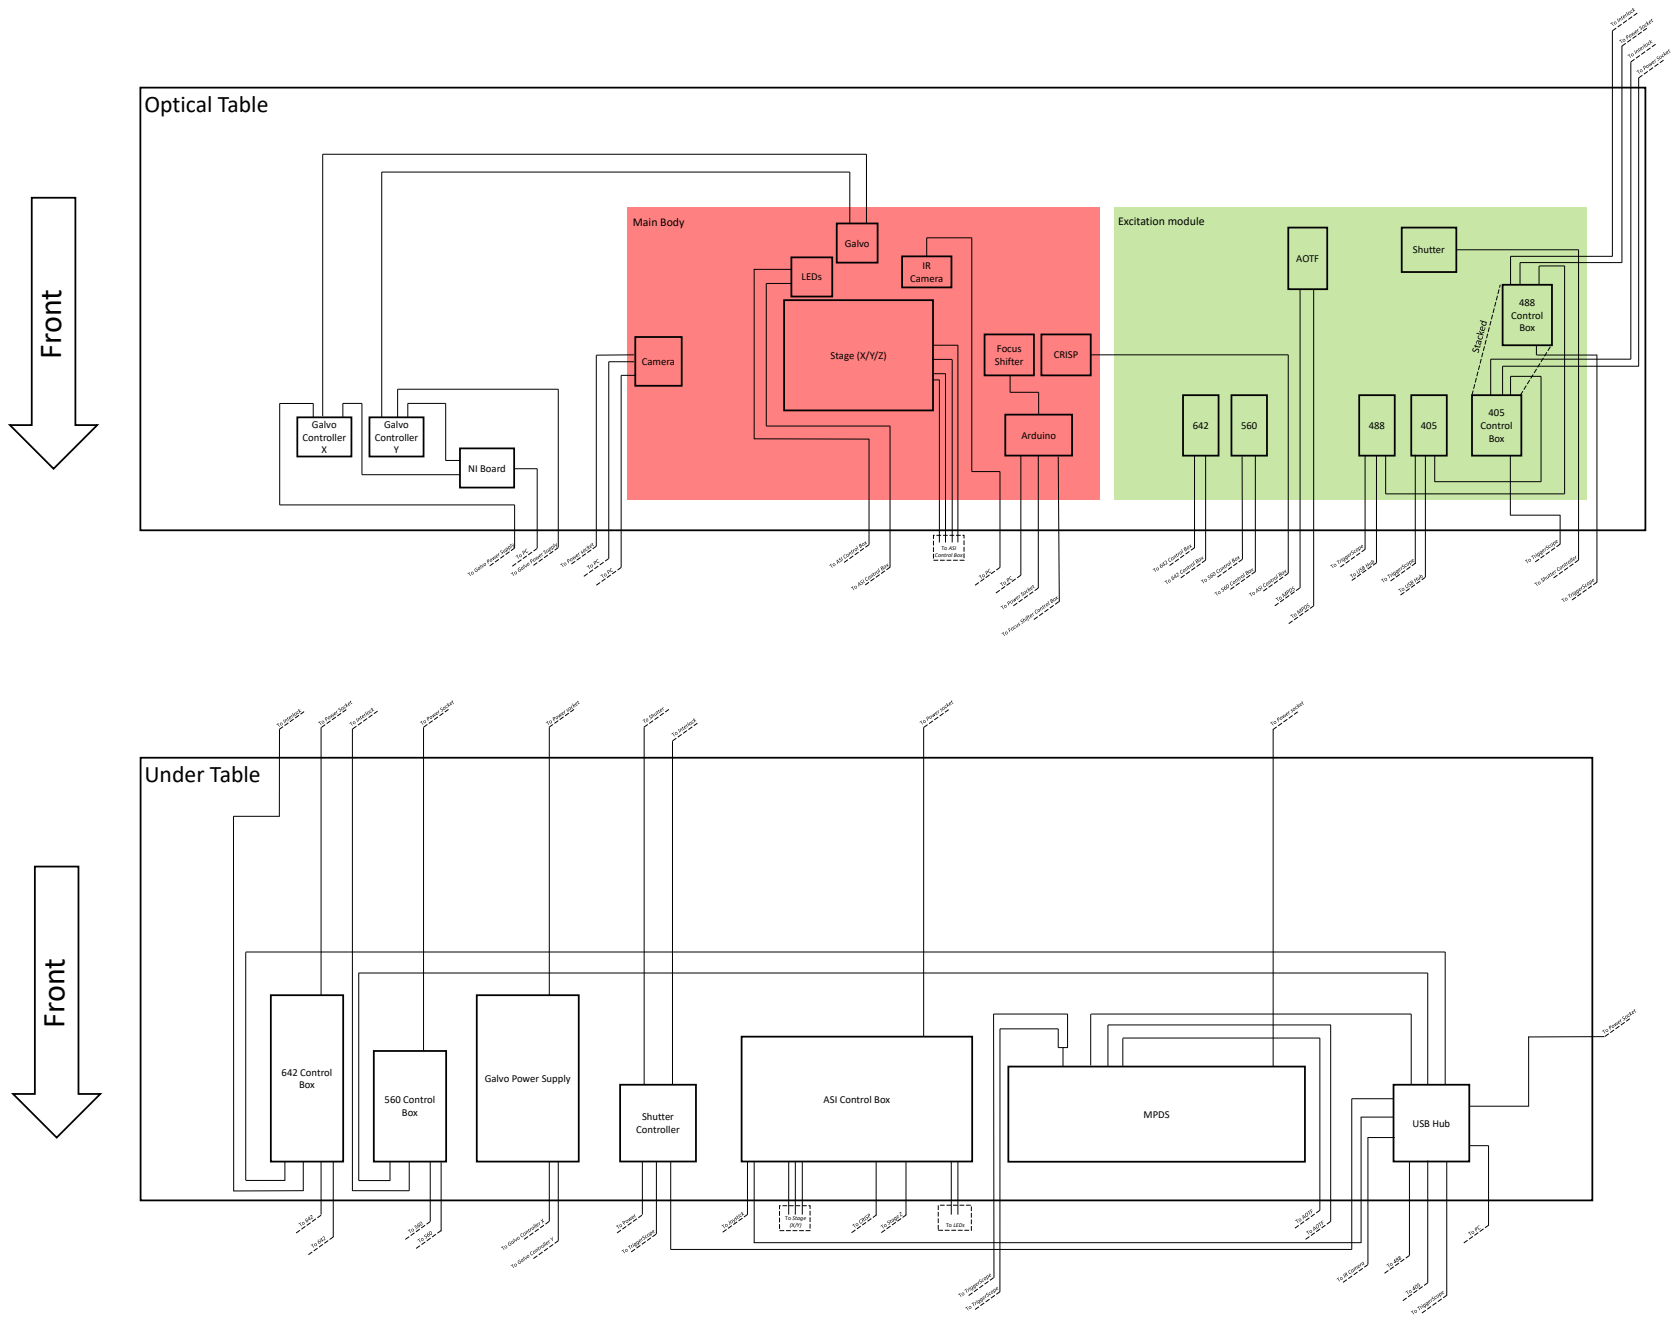
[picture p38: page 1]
AOTF; 405 Control Box; 488 Control Box; Shutter; Arduino; Stage (X/Y/Z); CRISP; Focus Shifter; Galvo; Galvo Controller X; Galvo Controller Y; Camera; IR Camera; NI Board; Under Table; 642 Control Box; 560 Control Box; MPDS; USB Hub; Shutter Controller; Main Body; Excitation module; LEDs; To Stage; To LEDs; Front Front; To ASI Control Box

Galvo Power Supply

ASI Control Box

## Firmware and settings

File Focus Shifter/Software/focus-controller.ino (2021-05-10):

/* 
Control stepper motor (defined as 200 steps/rev). 
Control via commands in the Arduino Serial Monitor (or other serial interface).
Move to absolute position. 
Saves current position, speed to memory & loads on startup.
Does not account for physical slippage of motor or object - need to 
implement fancy hardware limit switches etc for that
170724 Add a move up move down buttons

Device commands:
move val - moves device to val
speed val - sets speed to val (valid #s 0 - 255
pos? - returns current device position
speed? - return current device speed
setzero - sets current position as zero
stepsize
stepsize?
home
setmax
setmin
poslim   
*/


#include <Wire.h>
#include <Adafruit_MotorShield.h>
#include "utility/Adafruit_MS_PWMServoDriver.h"

#include <SoftwareSerial.h>   // We need this even if we're not using a SoftwareSerial object
                              // Due to the way the Arduino IDE compiles
#include "src/ArduinoSerialCommand/SerialCommand.h"
#include <EEPROM.h>
#define ADDRESS_POS 0
#define ADDRESS_SPEED 2
#define ADDRESS_MINPOS 3
#define ADDRESS_MAXPOS 5
#define STEP_PER_REV 200
#define MIN_STORE_CHANGE 100


// Create the motor shield object with the default I2C address
Adafruit_MotorShield AFMS = Adafruit_MotorShield(); 

// Connect a stepper motor with 200 steps per revolution (1.8 degree)
// to motor port #2 (M3 and M4)
Adafruit_StepperMotor *myMotor = AFMS.getStepper(STEP_PER_REV, 2);
int curPos,eepromPos;
byte curSpeed;
int stepSize = 5;
int  val; // Data received from the serial port
int maxPos,minPos;
SerialCommand SCmd;   // The demo SerialCommand object
const int kPinButton1 = 2;
const int kPinButton2 = 3;
const int HomeButton = 4;
const unsigned long kEEPROM_update_time = 5*1000;//10s
unsigned long timeCheck;

void setup() {
  Serial.begin(9600);           // set up Serial library at 9600 bps
  while (!Serial) {
    ; // wait for serial port to connect. Needed for native USB port only
  }
  Serial.println("Stepper connected");

  EEPROM.get(ADDRESS_POS, curPos);
  eepromPos = curPos;
  Serial.println("Current position:");
  Serial.println(curPos, DEC);    //This may print 'ovf, nan' if the data inside the EEPROM is not a valid float.
  EEPROM.get(ADDRESS_SPEED, curSpeed);
  Serial.println("Current speed:");
  Serial.println(curSpeed, DEC);    //This may print 'ovf, nan' if the data inside the EEPROM is not a valid float.
  EEPROM.get(ADDRESS_MINPOS, minPos);
  EEPROM.get(ADDRESS_MAXPOS, maxPos);
  Serial.println("A");
   
  AFMS.begin();  // create with the default frequency 1.6KHz
  myMotor->setSpeed(curSpeed);  // 10 rpm   

   // Setup callbacks for SerialCommand commands // Have to change define in serial command max # of commands to 20
  SCmd.addCommand("move",move);       // move
  SCmd.addCommand("speed",speed);       
  SCmd.addCommand("pos?",reportPos);   
  SCmd.addCommand("speed?",reportSpeed);    
  SCmd.addCommand("setzero",setzero);    
  SCmd.addCommand("stepsize",relStepSize);    
  SCmd.addCommand("stepsize?",reportStepSize);  
  SCmd.addCommand("home",home);  
  SCmd.addCommand("setmax",setmax);
  SCmd.addCommand("setmin",setmin);
  SCmd.addCommand("poslim?",getPosLim);          
  SCmd.addCommand("help",help);  
          
  SCmd.addDefaultHandler(unrecognized);  // Handler for command that isn't matched  (says "?") 

  //setup the push buttons 
  pinMode(kPinButton1, INPUT);
  pinMode(kPinButton2, INPUT);
  pinMode(HomeButton, INPUT);
  digitalWrite(kPinButton1, HIGH);
  digitalWrite(kPinButton2, HIGH);
  digitalWrite(HomeButton, HIGH);

  //setup the time check
  timeCheck = millis();
}

void loop()
{  
  SCmd.readSerial();     // We don't do much, just process serial commands
  if(digitalRead(kPinButton1)==LOW){
     //Serial.println("Motor UP");
     relmove(stepSize);
     //delay(20);//optional delay if button pressed too much
  }
  if(digitalRead(kPinButton2)==LOW){
     //Serial.println("Motor DOWN");
     relmove(-1*stepSize);
     //delay(20);//optional delay if button pressed too much
  }
  if(digitalRead(HomeButton)==LOW){
     //Serial.println("Going Home");
     home();
     //delay(20);//optional delay if button pressed too much
  }


  // update the eeprom every N s 
  // since we dont update it during manual moves to avoid 
  // too many eeprom writes
  //this only updates the eeprom if value has actually changed
  if (millis() - timeCheck > kEEPROM_update_time){
    updateEEPROMPos();
    timeCheck = millis();
  }
  
  
}

void move(){
  int pos;  
  char *arg; 

  arg = SCmd.next(); 
  if (arg != NULL){
    pos =atol(arg); 
    moveMotor(pos);
    updateEEPROMPos();
    Serial.println("A"); 

  } else{
    Serial.println("?"); 
  }
}

void moveMotor(int pos){
    pos = constrain(pos,minPos,maxPos);// software hard limits to avoid motor crash
    int nStep = pos-curPos;
    if (nStep>=0){
      myMotor->step(nStep, FORWARD, SINGLE); 
      
    }
    else {
      myMotor->step(-nStep, BACKWARD, SINGLE); 
    }
     
    curPos=pos;
}

void updateEEPROMPos(){// update the eeprom, as long as its actually changed
  if (curPos != eepromPos){
    eepromPos = curPos;
    EEPROM.put(ADDRESS_POS, eepromPos);  
  }
}


// this is the move function for manual moves
// doesnt update the eeprom as dont want to do too many writes
// instead we have a function that checks every N s if we need to update the 
// eeprom
void relmove(int relStep){
  int posFinal;
  posFinal = curPos + relStep;
  moveMotor(posFinal);
}

void reportPos(){ 
  Serial.println(curPos);
}

void reportSpeed(){ 
  Serial.println(curSpeed);
}

void speed(){
  int s;  
  char *arg; 

  arg = SCmd.next(); 
  if (arg != NULL){ 
    s =atol(arg); 
    myMotor->setSpeed(s);

    curSpeed=s;
    EEPROM.put(ADDRESS_SPEED, curSpeed);
    Serial.println("A"); 
  } 
}

void relStepSize(){
  int s;  
  char *arg; 

  arg = SCmd.next(); 
  if (arg != NULL){ 
    s =atol(arg); 
    stepSize = s;

    Serial.println("A"); 
  } 
}
void reportStepSize(){ 
  Serial.println(stepSize);
}
void setzero(){// set current position as zero location
  maxPos = maxPos - curPos;
  minPos = minPos - curPos;
  curPos=0;
  EEPROM.put(ADDRESS_POS, curPos);
  Serial.println("A"); 
}

void home(){
  moveMotor(0);
  Serial.println("A"); 
}

// This gets set as the default handler, and gets called when no other command matches. 
void unrecognized()
{
  Serial.println("?"); 
}

void setmax(){
  int s;  
  char *arg; 

  arg = SCmd.next(); 
  if (arg != NULL){ 
    s =atol(arg); 
    maxPos = s;
  } else  {
    maxPos = curPos;
  }
  
  EEPROM.put(ADDRESS_MAXPOS, maxPos);
  Serial.println("A"); 
}

void getPosLim(){
   Serial.println("Min pos:");
   Serial.println(minPos); 
   Serial.println("Max pos:");
   Serial.println(maxPos);
}

void setmin(){
  int s;  
  char *arg; 

  arg = SCmd.next(); 
  if (arg != NULL){ 
    s =atol(arg); 
    minPos = s;
  } else  {
    minPos = curPos;
  }
  
  EEPROM.put(ADDRESS_MINPOS, minPos);
  Serial.println("A"); 
}

void help(){
  Serial.println("Device commands:");
  Serial.println("move val - moves device to val");
  Serial.println("speed val - sets speed to val (valid #s 0 - 255)");
  Serial.println("pos? - returns current device position");
  Serial.println("speed? - return current device speed");
  Serial.println("setzero - sets current position as zero");
  Serial.println("stepsize");
  Serial.println("stepsize?");
  Serial.println("home");
  Serial.println("setmax");
  Serial.println("setmin");
  Serial.println("poslim");
}

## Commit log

2020-11-02 Added .STEP files
    [Beam-Expansion-Module.step, Excitation-Module.step, Main-Body.step]
2020-11-02 Added camera mounts
    [Camera mount (With OptoSplit).stl, Camera mount.stl]
2020-11-02 Adding 2D drawings of incubation chamber parts
    [Front-Access-Cover-Bottom.dxf, Front-Access-Cover-Top.dxf, Front-Panel.dxf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]
2020-11-03 Create Microscope-incubation-chamber v79.step
    [Microscope-incubation-chamber v79.step]
2020-11-03 altered file structure
    [AOTF Mount.stl, Astig-Box-Body.stl, Astig-Box-Lid.stl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]
2020-11-05 adding switch
2020-11-09 Add Arduino Box
    [Arduino-Box-Bottom.stl, Arduino-Box-Top.stl]
2020-11-09 Edited Switch Images
2020-11-11 Updated Arduino Box
    [Arduino-Box-Bottom.stl, Arduino-Box-Top.stl]
2020-11-27 added home button function to arduino code
2020-12-13 reorganised file structure
    [AOTF Mount.stl, Arduino Box Bottom.stl, Arduino Box Top.stl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]
2020-12-20 removed outdated parts
    [Front-Access-Cover-Bottom.dxf, Front-Access-Cover-Top.dxf, Front-Panel.dxf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]
2020-12-22 added Box Drawings
    [Incubation-Chamber-Back-Access-Hatch.dxf, Incubation-Chamber-Back-Bottom-Heater-Mount.dxf, Incubation-Chamber-Back-Excitation-Hatch.dxf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]
2020-12-23 Create Aluminium Mount.step
    [Aluminium Mount.step]
2020-12-23 populated from sub-modules
    [Arduino Box Bottom.stl, Arduino Box Top.stl, Autofocus-Path-Cover.stl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]
2020-12-24 added Alignment Laser Designs
    [Aignment-Laser Drawing.dxf, Aignment-Laser v6.step]
2020-12-24 Update Aignment-Laser Drawing.dxf
    [Aignment-Laser Drawing.dxf]
2020-12-29 updated alignment laser
    [Aignment-Laser Drawing.dxf, Aignment-Laser v6.step, Aignment-Laser.step]
2020-12-29 Moved to separate folder
    [Aignment-Laser Drawing.dxf, Aignment-Laser.step]
2021-02-16 Updated mm config files
    [BlackflyCamera.cfg, LifeHack_MMconfig.cfg]
2021-04-01 reduced 100mm beam expansion lens diameter
    [LifeHack-Parts.xlsx]
2021-05-07 Lengthened ImLock path
    [Autofocus-Path-Cover.stl, ImLock-cover.stl]
2021-05-07 updated IR-LED control
    [LifeHack_MMconfig.cfg]
2021-10-14 Changed FS Rocker Switch
    [LifeHack-Parts.xlsx]
